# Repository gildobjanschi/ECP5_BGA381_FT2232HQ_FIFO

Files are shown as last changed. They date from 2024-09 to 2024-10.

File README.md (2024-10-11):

# ECP5/FT2232HQ Software & Hardware
This project implements a High Speed USB device using a FT2232HQ operating in synchronous FIFO mode coupled with a Lattice Semiconductor ECP5 FPGA. 

## Software
Read all the details of the bring-up steps and test code in the [Wiki](https://github.com/gildobjanschi/ECP5_BGA381_FT2232HQ_FIFO/wiki).

The diagram below will help you understand the software architecture and navigate the Verilog and C source code a bit easier.

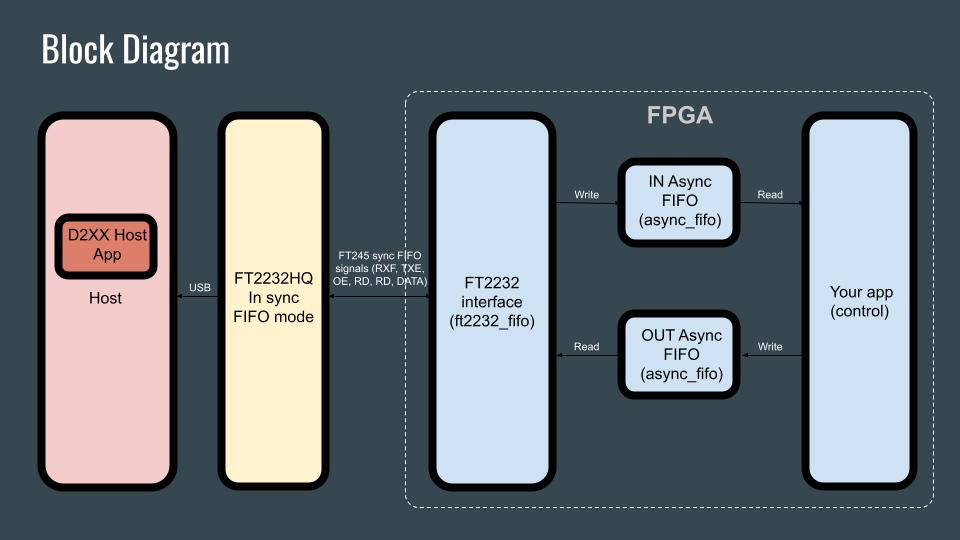
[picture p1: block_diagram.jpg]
Block Diagram


## Hardware
The board is fully functional. An [extension board](https://github.com/gildobjanschi/ECP5_BGA381_FT2232HQ_FIFO_EXT) was developed to help validate the design.

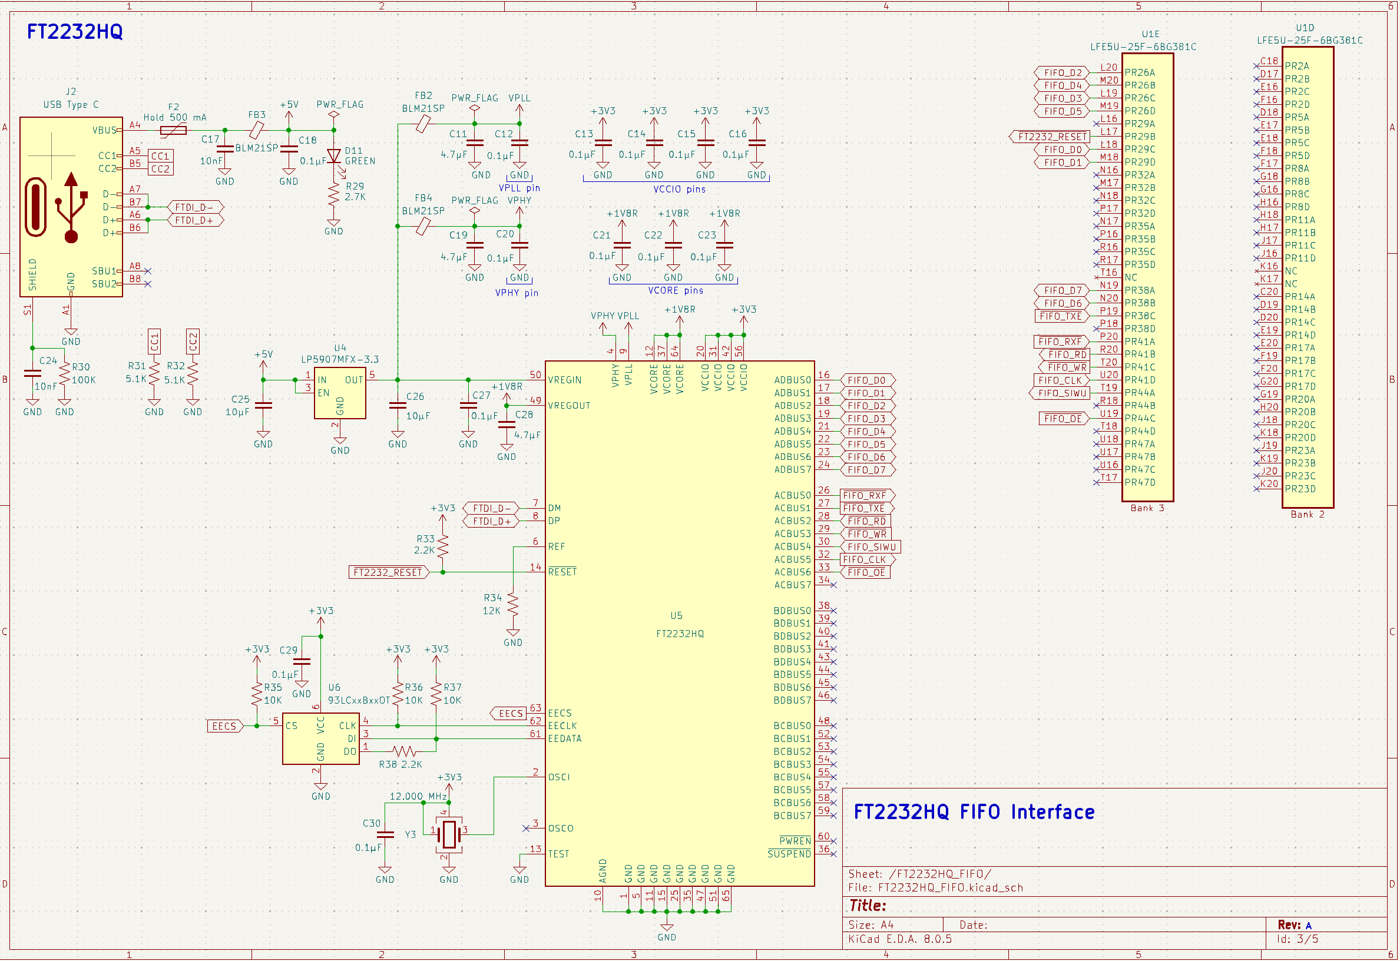
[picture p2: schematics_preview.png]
[](https://github.com/gildobjanschi/ECP5_BGA381_FT2232HQ_FIFO/blob/main/kicad/ECP5.pdf)

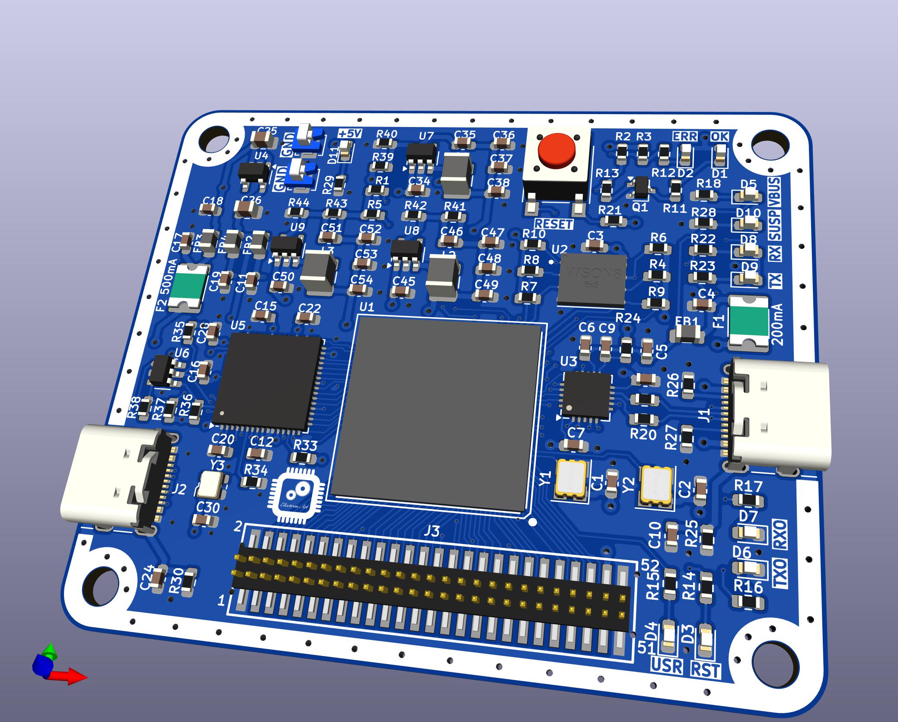
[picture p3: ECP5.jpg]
Board rendering


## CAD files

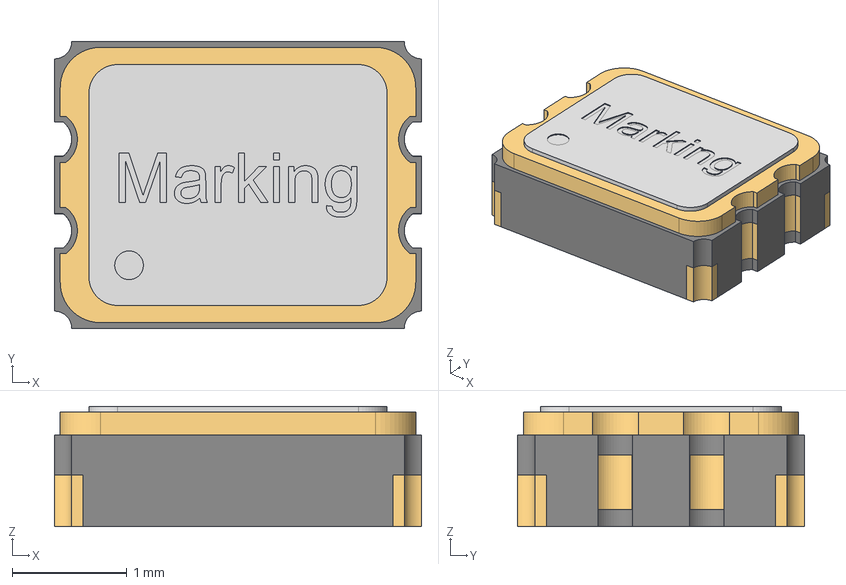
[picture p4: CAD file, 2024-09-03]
3dmodels/Wurth_830207659009.stp
3.20 x 2.50 x 1.05 mm
Pins
Cover

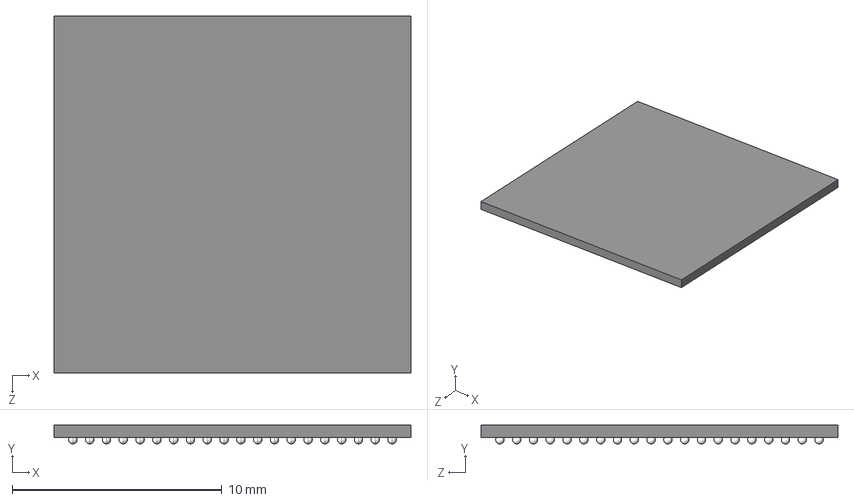
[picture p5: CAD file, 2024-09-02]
3dmodels/LFE5UM-85F-8BG381C.STEP
17.0 x 0.9 x 17.0 mm

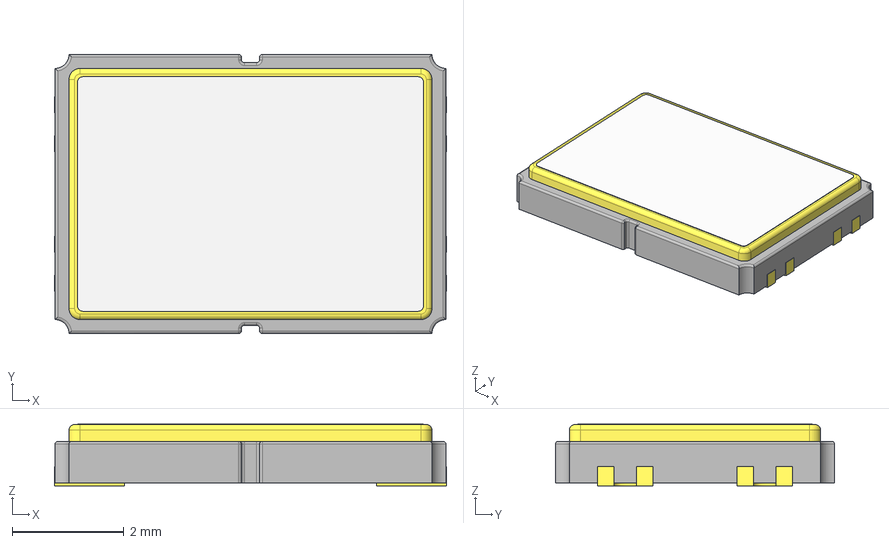
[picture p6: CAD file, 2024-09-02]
3dmodels/CRYSTAL_7050-4.step
7.02 x 5.00 x 1.11 mm
Pin
Pin001
Pin002
Pin003

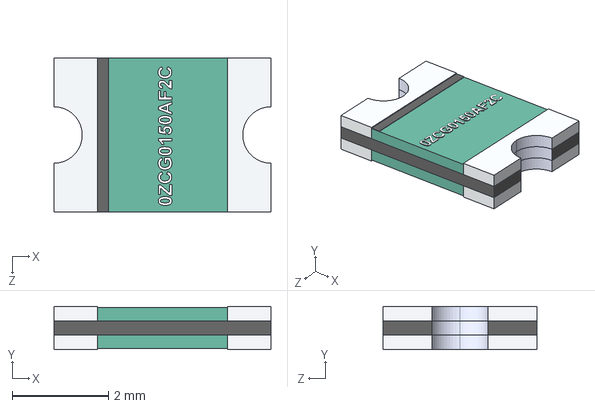
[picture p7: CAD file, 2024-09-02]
3dmodels/0ZCG-0_70mm.STEP
4.50 x 0.9 x 3.20 mm

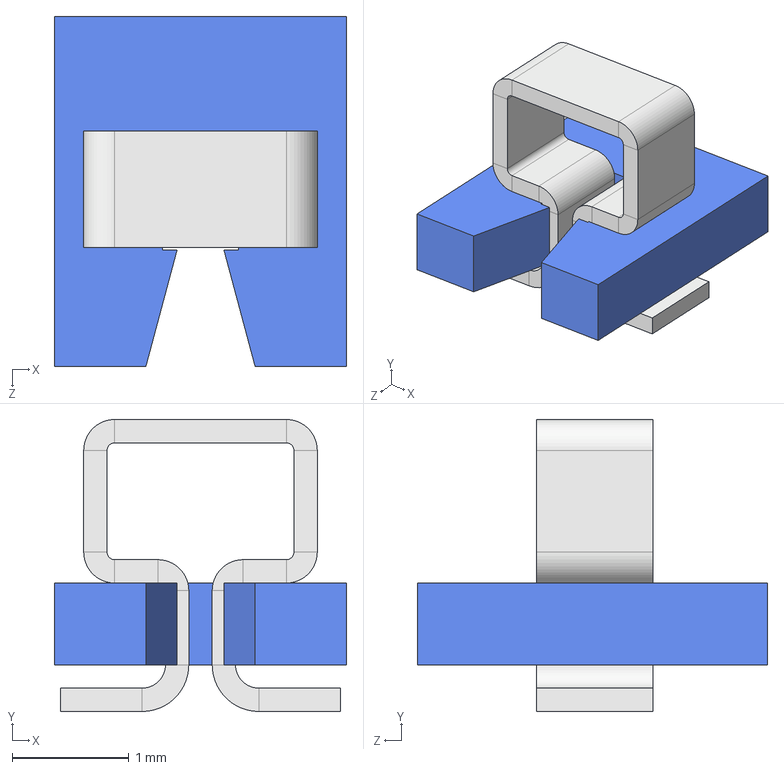
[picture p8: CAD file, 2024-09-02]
3dmodels/5197TR.step
2.50 x 2.50 x 3.00 mm
5197_insulation
5190_assembled contact

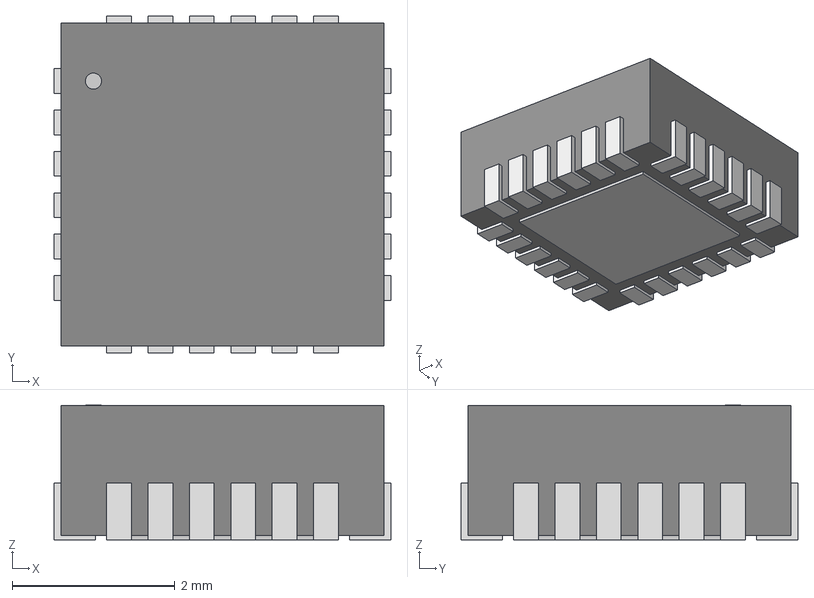
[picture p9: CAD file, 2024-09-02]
3dmodels/QFN24_4X4MC_MCH.step
4.14 x 4.14 x 1.65 mm

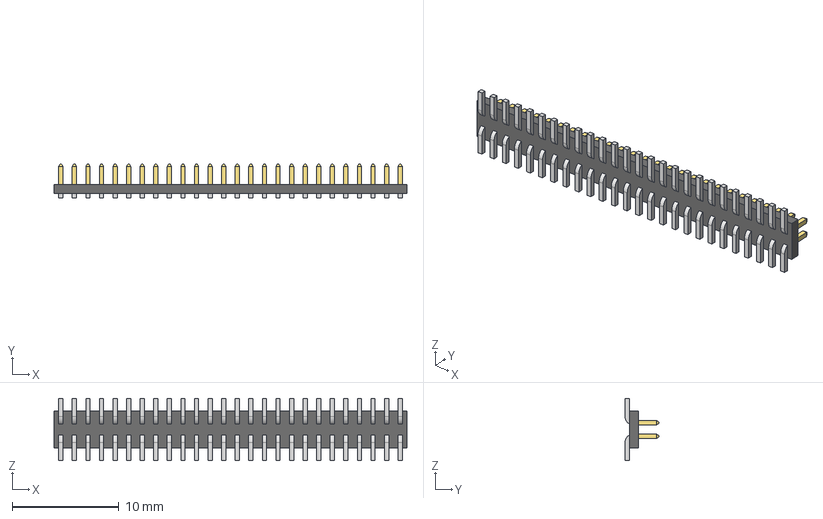
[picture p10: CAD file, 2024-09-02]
3dmodels/SAMTEC-FTS-126-02-X-DV.step
33.0 x 3.18 x 5.84 mm
FTS-126-02-L-DV_body
FTS-126-02-L-DV_pins1
FTS-126-02-L-DV_pins2

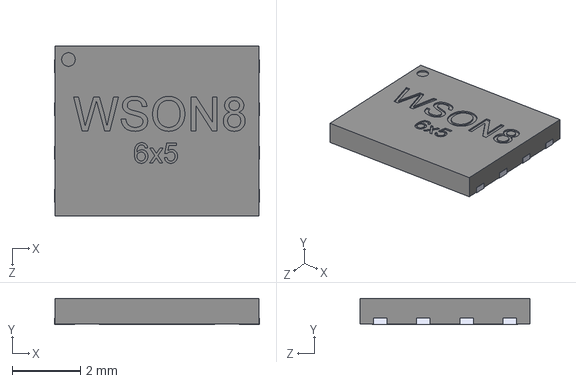
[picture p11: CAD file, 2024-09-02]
3dmodels/WSON8-6x5.STEP
6.02 x 0.77 x 5.00 mm

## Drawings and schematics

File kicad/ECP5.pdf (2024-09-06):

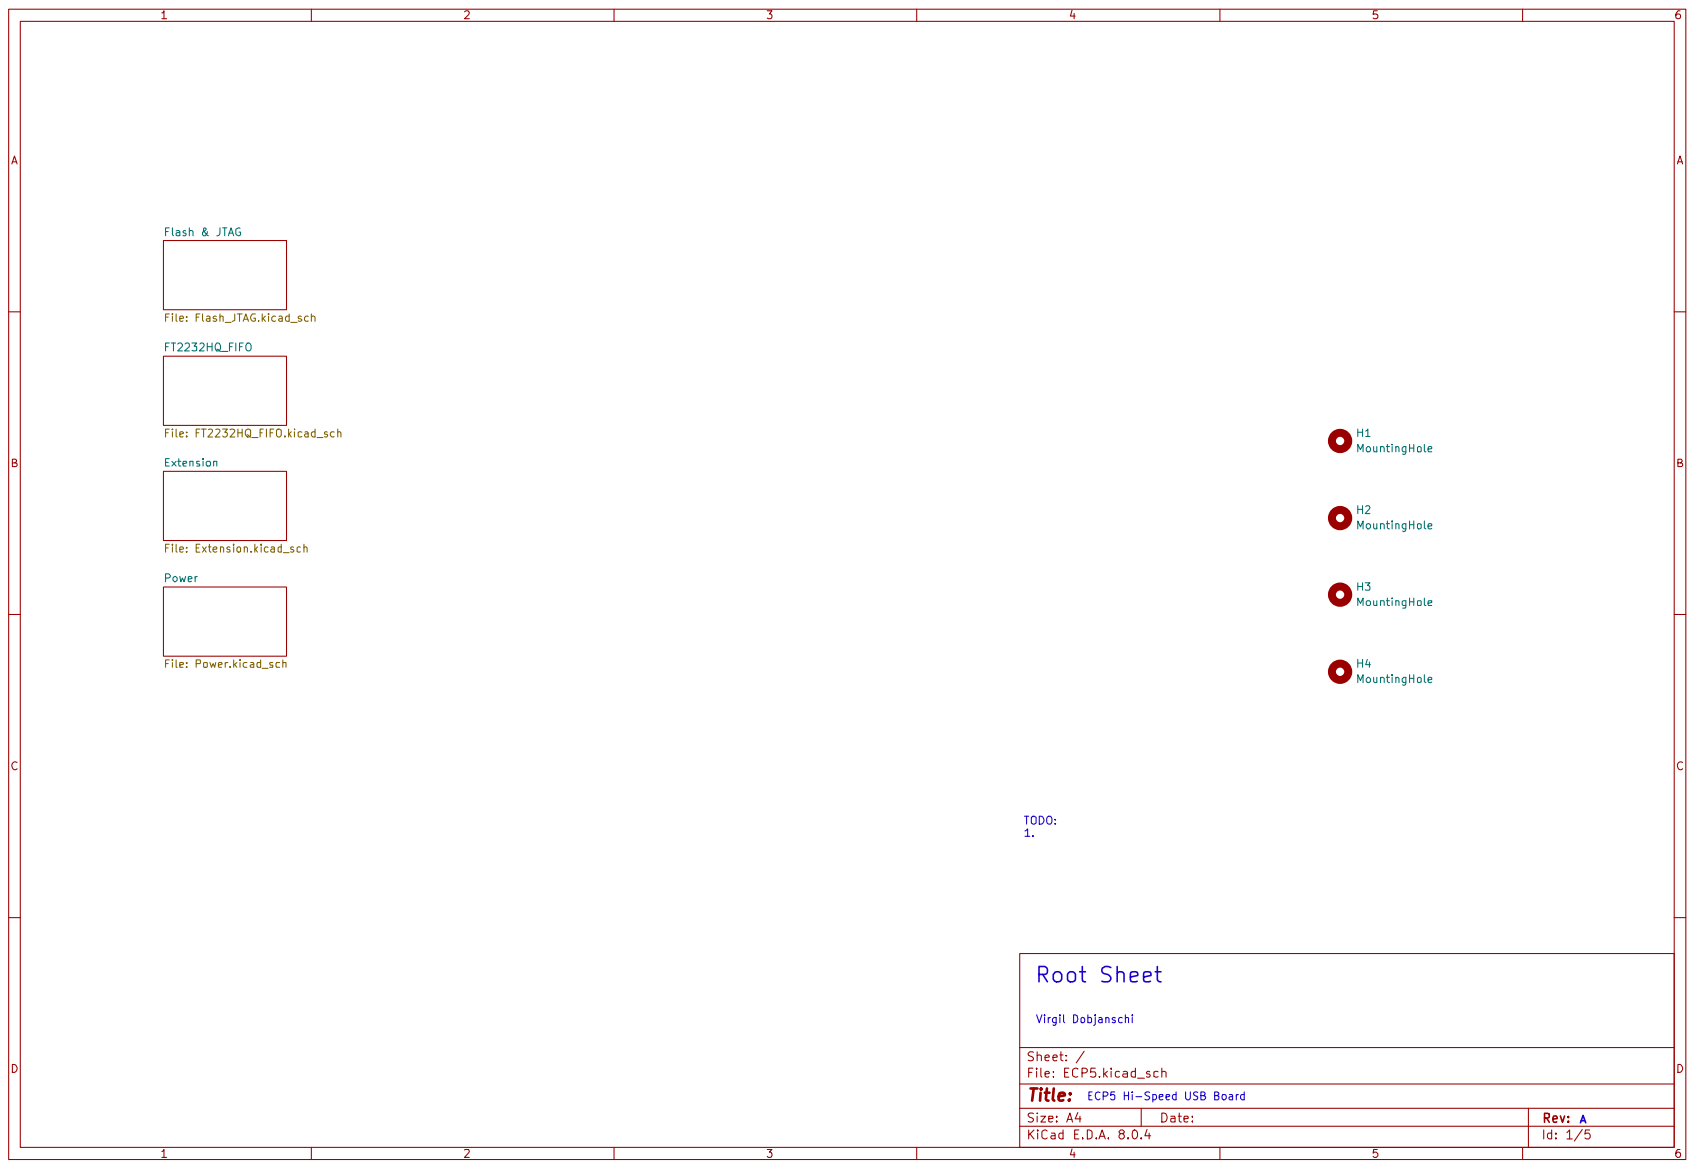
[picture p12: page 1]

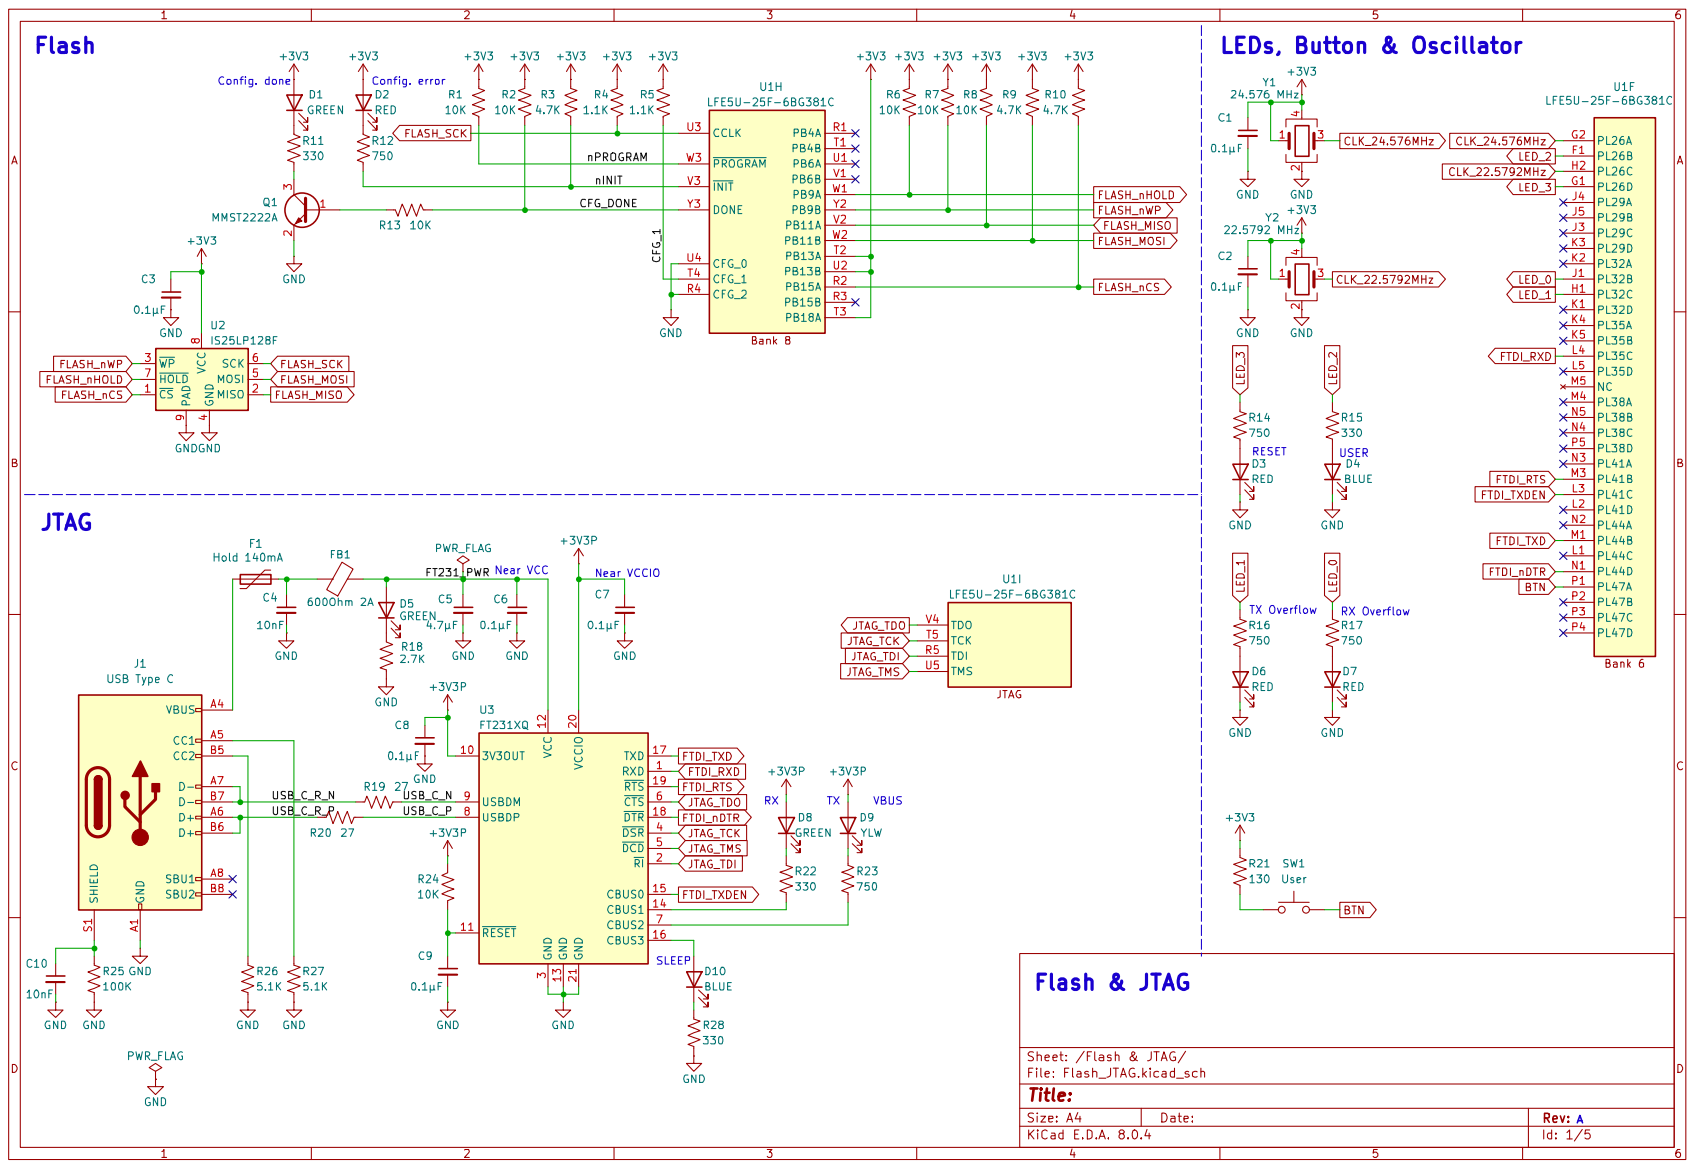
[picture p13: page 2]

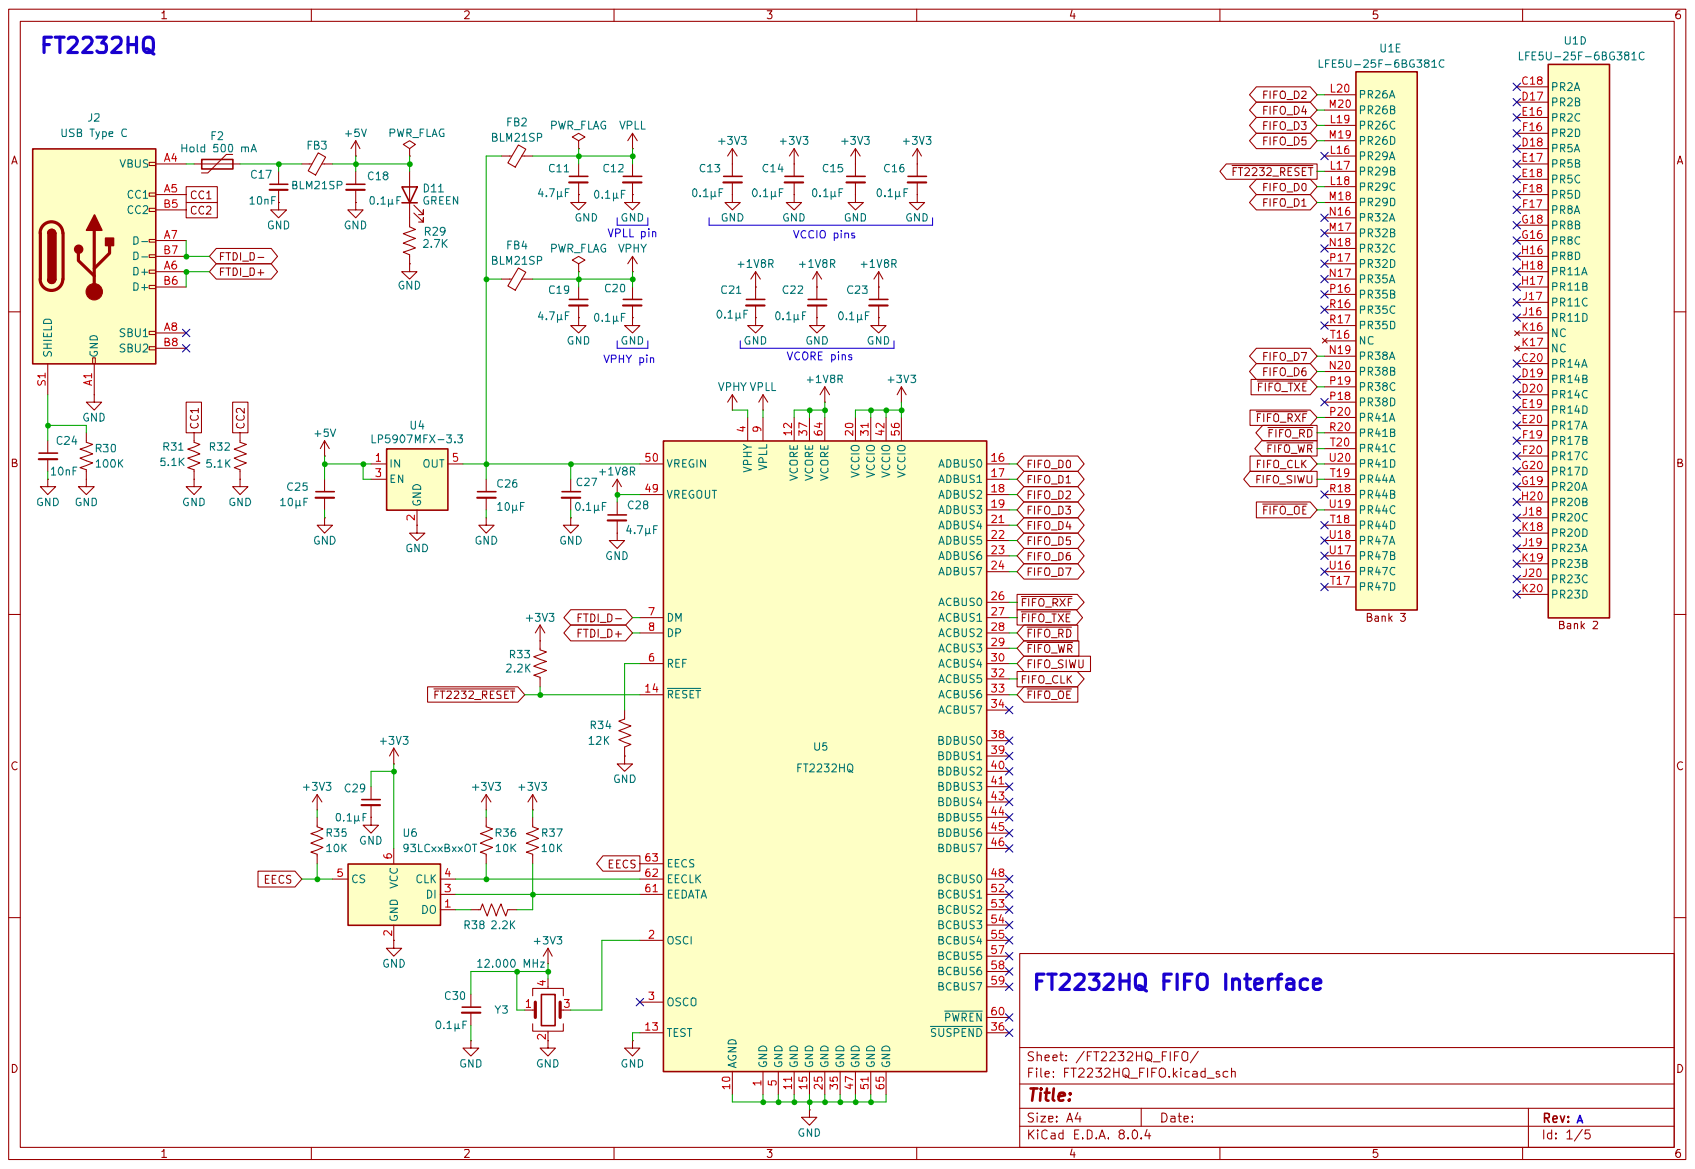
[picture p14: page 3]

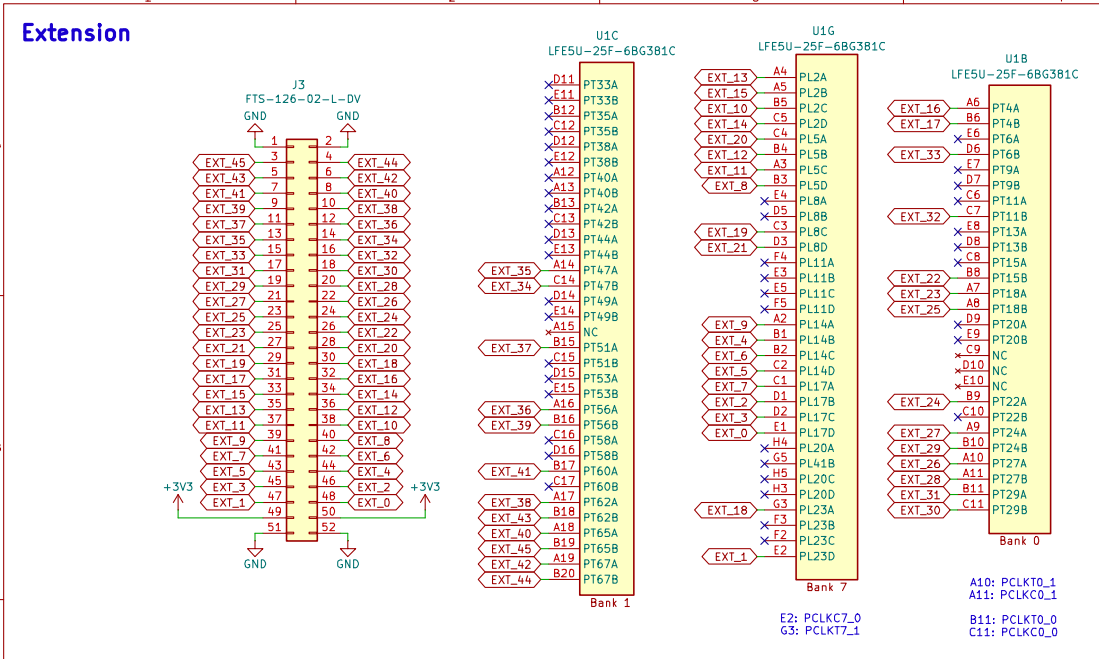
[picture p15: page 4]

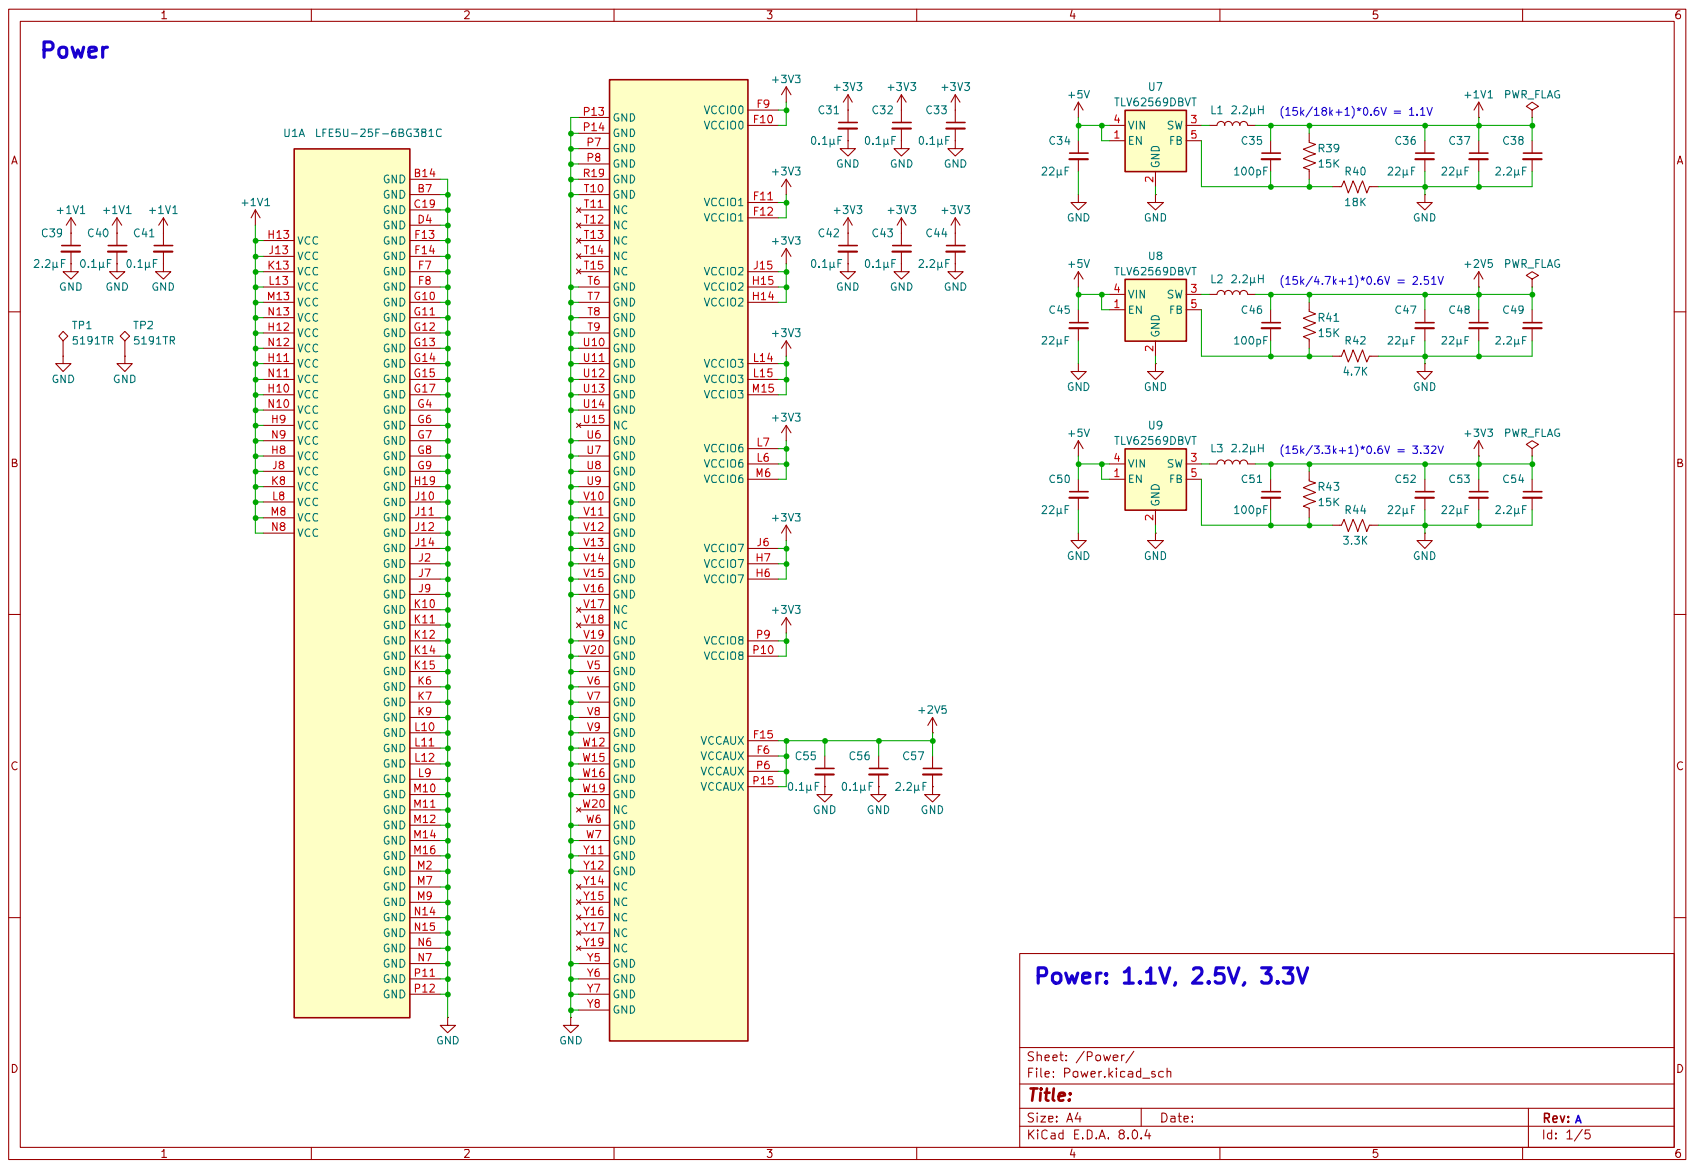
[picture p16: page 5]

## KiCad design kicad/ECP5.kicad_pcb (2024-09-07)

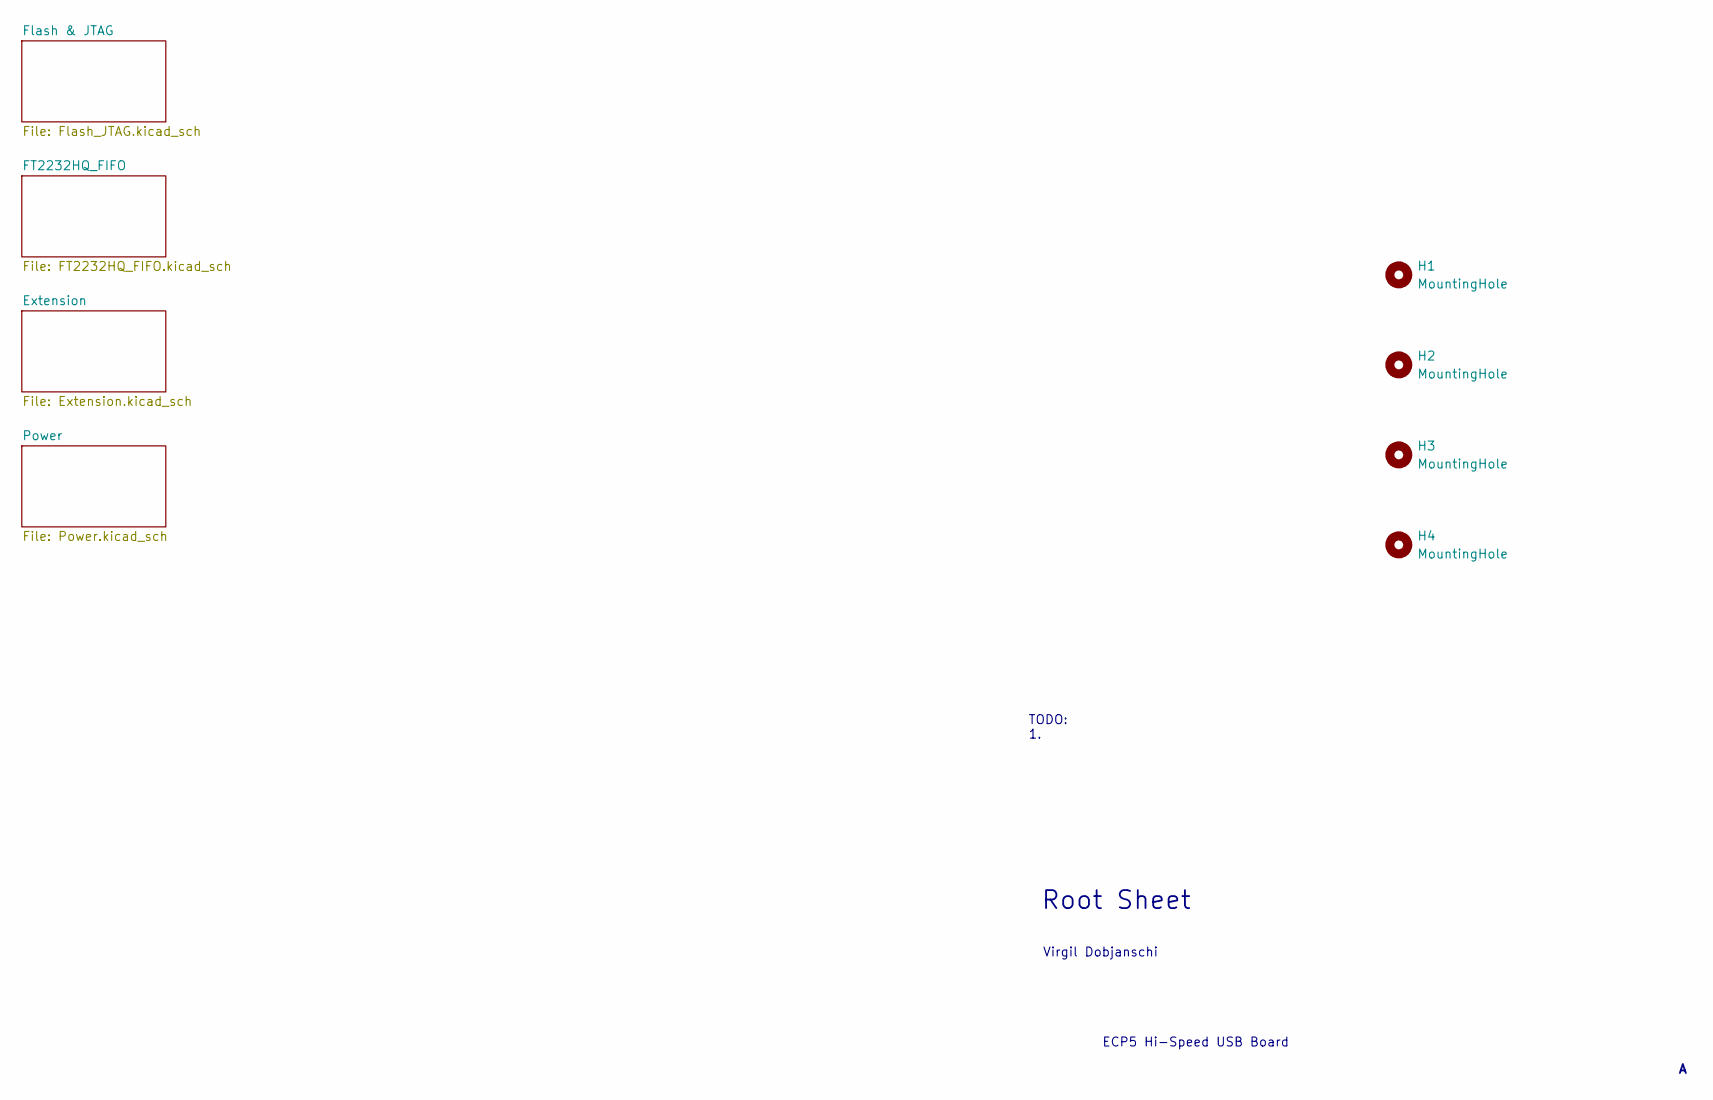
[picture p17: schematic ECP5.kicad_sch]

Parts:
H1, H2, H3, H4: MountingHole; MountingHole_3.2mm_M3

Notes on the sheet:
ECP5 Hi-Speed USB Board
Root Sheet
Virgil Dobjanschi
TODO: 1.

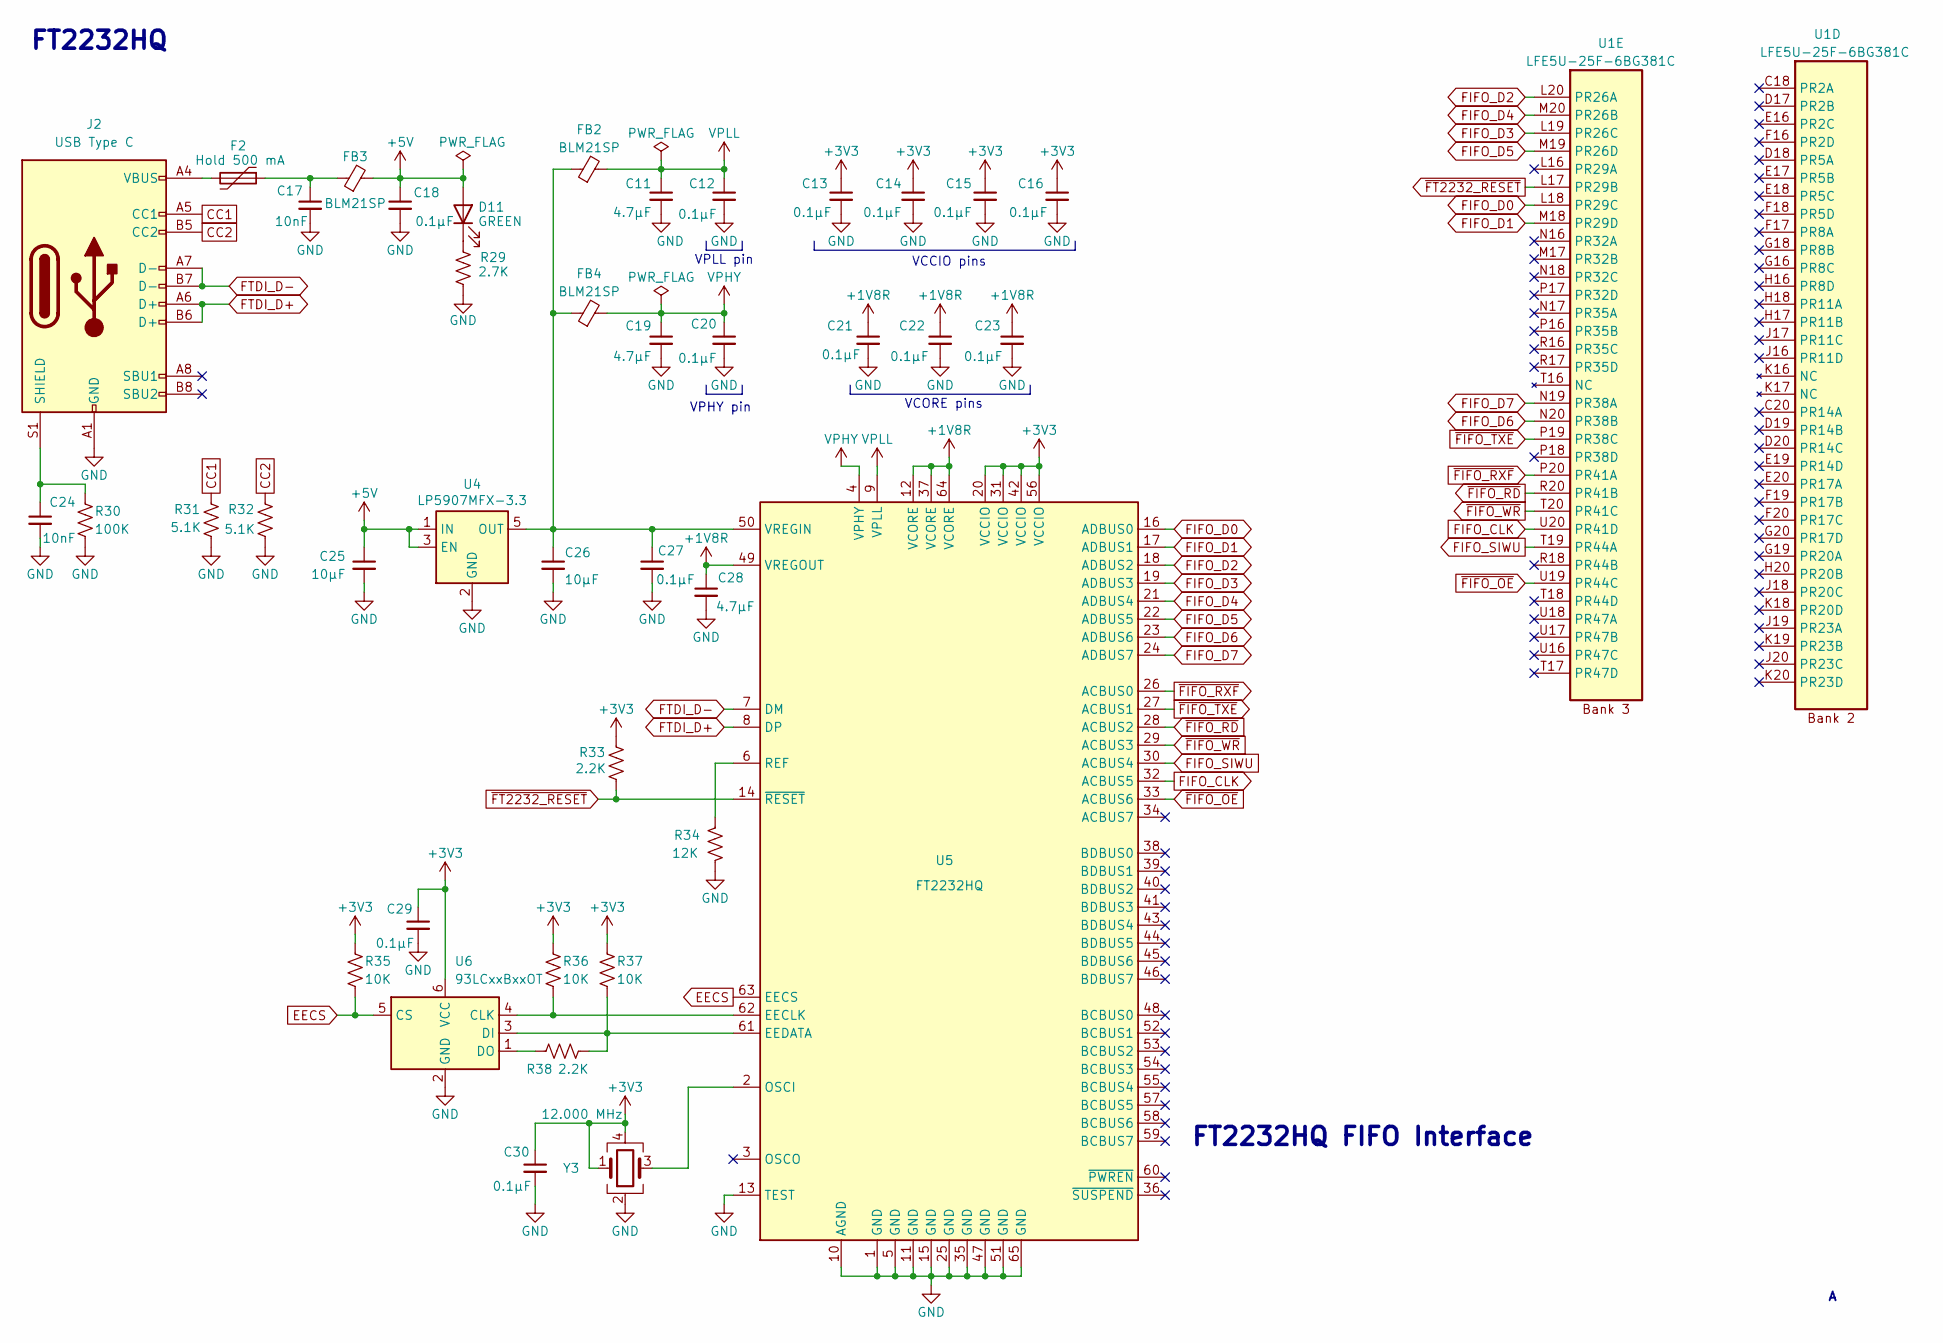
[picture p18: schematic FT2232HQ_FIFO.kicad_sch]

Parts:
C11, C19, C28: 4.7µF; C_0603_1608Metric; MPN CL10A475KP8NNNC
C12, C13, C14, C15, C16, C18, C20, C21, C22, C23, C27, C29, C30: 0.1µF; C_0603_1608Metric; MPN CL10B104KB8NNNC
C17, C24: 10nF; C_0603_1608Metric; MPN CL10B103KB8NNWC
C25, C26: 10µF; C_0805_2012Metric; MPN CL21B106KOQNNNE
D11: GREEN; LED_0603_1608Metric; MPN APT1608LZGCK
F2: Hold 500 mA; Fuse_1812_4532Metric; MPN 0ZCG0050AF2C
FB2, FB3, FB4: BLM21SP; L_0805_2012Metric; MPN BLM21SP601SN1D
J2: USB Type C; USB_C_Receptacle_GCT_USB4105-xx-A_16P_TopMnt_Horizontal; MPN USB4105-GF-A-120
R29: 2.7K; R_0603_1608Metric; MPN ERJ-3EKF2701V
R30: 100K; R_0603_1608Metric; MPN ERJ-3EKF1003V
R31, R32: 5.1K; R_0603_1608Metric; MPN ERJ-3EKF5101V
R33, R38: 2.2K; R_0603_1608Metric; MPN ERJ-3EKF2201V
R34: 12K; R_0603_1608Metric; MPN ERJ-3EKF1202V
R35, R36, R37: 10K; R_0603_1608Metric; MPN ERJ-3EKF1002V
U1: LFE5U-25F-6BG381C; BGA-381_pitch0.8mm_dia0.4mm; MPN LFE5U-25F-6BG381C
U4: LP5907MFX-3.3; SOT-23-5; MPN LP5907MFX-3.3/NOPB
U5: FT2232HQ; QFN-64-1EP_9x9mm_P0.5mm_EP4.35x4.35mm; MPN FT2232HQ-REEL
U6: 93LCxxBxxOT; SOT-23-6; MPN 93LC56BT-I/OT
Y3: 12.000 MHz; Oscillator_SMD_ECS_2520MV-xxx-xx-4Pin_2.5x2.0mm; MPN SG-210STF 12.0000ML3

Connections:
+1V8R: C21.1, C22.1, C23.1, C28.1, U5.12 (VCORE), U5.37 (VCORE), U5.49 (VREGOUT), U5.64 (VCORE)
+3V3: C13.1, C14.1, C15.1, C16.1, C29.1, C30.1, R33.1, R35.1, R36.1, R37.1, U5.20 (VCCIO), U5.31 (VCCIO), U5.42 (VCCIO), U5.56 (VCCIO), U6.6 (VCC), Y3.1, Y3.4; also elsewhere on the board
+5V: C18.1, C25.1, D11.2 (A), FB3.2, U4.1 (IN), U4.3 (EN); also elsewhere on the board
CC1: J2.A5 (CC1), R31.1
CC2: J2.B5 (CC2), R32.1
EECS: R35.2, U5.63 (EECS), U6.5 (CS)
FIFO_CLK: U1.U20 (PR41D), U5.32 (ACBUS5)
FIFO_D0: U1.L18 (PR29C), U5.16 (ADBUS0)
FIFO_D1: U1.M18 (PR29D), U5.17 (ADBUS1)
FIFO_D2: U1.L20 (PR26A), U5.18 (ADBUS2)
FIFO_D3: U1.L19 (PR26C), U5.19 (ADBUS3)
FIFO_D4: U1.M20 (PR26B), U5.21 (ADBUS4)
FIFO_D5: U1.M19 (PR26D), U5.22 (ADBUS5)
FIFO_D6: U1.N20 (PR38B), U5.23 (ADBUS6)
FIFO_D7: U1.N19 (PR38A), U5.24 (ADBUS7)
FIFO_SIWU: U1.T19 (PR44A), U5.30 (ACBUS4)
FTDI_D+: J2.A6 (D+), J2.B6 (D+), U5.8 (DP)
FTDI_D-: J2.A7 (D-), J2.B7 (D-), U5.7 (DM)
GND: C11.2, C12.2, C13.2, C14.2, C15.2, C16.2, C17.2, C18.2, C19.2, C20.2, C21.2, C22.2, C23.2, C24.2, C25.2, C26.2, C27.2, C28.2, C29.2, C30.2, J2.A1 (GND), J2.A12 (GND), J2.B1 (GND), J2.B12 (GND), R29.2, R30.2, R31.2, R32.2, R34.2, U4.2 (GND), U5.1 (GND), U5.5 (GND), U5.10 (AGND), U5.11 (GND), U5.13 (TEST), U5.15 (GND), U5.25 (GND), U5.35 (GND), U5.47 (GND), U5.51 (GND), U5.65 (GND), U6.2 (GND), Y3.2; also elsewhere on the board
unnamed: C17.1, F2.1, FB3.1
unnamed: D11.1 (K), R29.1
unnamed: F2.2, J2.A4 (VBUS), J2.A9 (VBUS), J2.B4 (VBUS), J2.B9 (VBUS)
unnamed: C24.1, J2.S1 (SHIELD), R30.1
unnamed: C26.1, C27.1, FB2.1, FB4.1, U4.5 (OUT), U5.50 (VREGIN)
unnamed: R36.2, U5.62 (EECLK), U6.4 (CLK)
unnamed: R37.2, R38.2, U5.61 (EEDATA), U6.3 (DI)
unnamed: U5.2 (OSCI), Y3.3
unnamed: R34.1, U5.6 (REF)
unnamed: R38.1, U6.1 (DO)
VPHY: C19.1, C20.1, FB4.2, U5.4 (VPHY)
VPLL: C11.1, C12.1, FB2.2, U5.9 (VPLL)
~FIFO_OE: U1.U19 (PR44C), U5.33 (ACBUS6)
~FIFO_RD: U1.R20 (PR41B), U5.28 (ACBUS2)
~FIFO_RXF: U1.P20 (PR41A), U5.26 (ACBUS0)
~FIFO_TXE: U1.P19 (PR38C), U5.27 (ACBUS1)
~FIFO_WR: U1.T20 (PR41C), U5.29 (ACBUS3)
~FT2232_RESET: R33.2, U1.L17 (PR29B), U5.14 (~RESET)

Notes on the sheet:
VPHY pin
VPLL pin
FT2232HQ
VCCIO pins
VCORE pins
FT2232HQ FIFO Interface

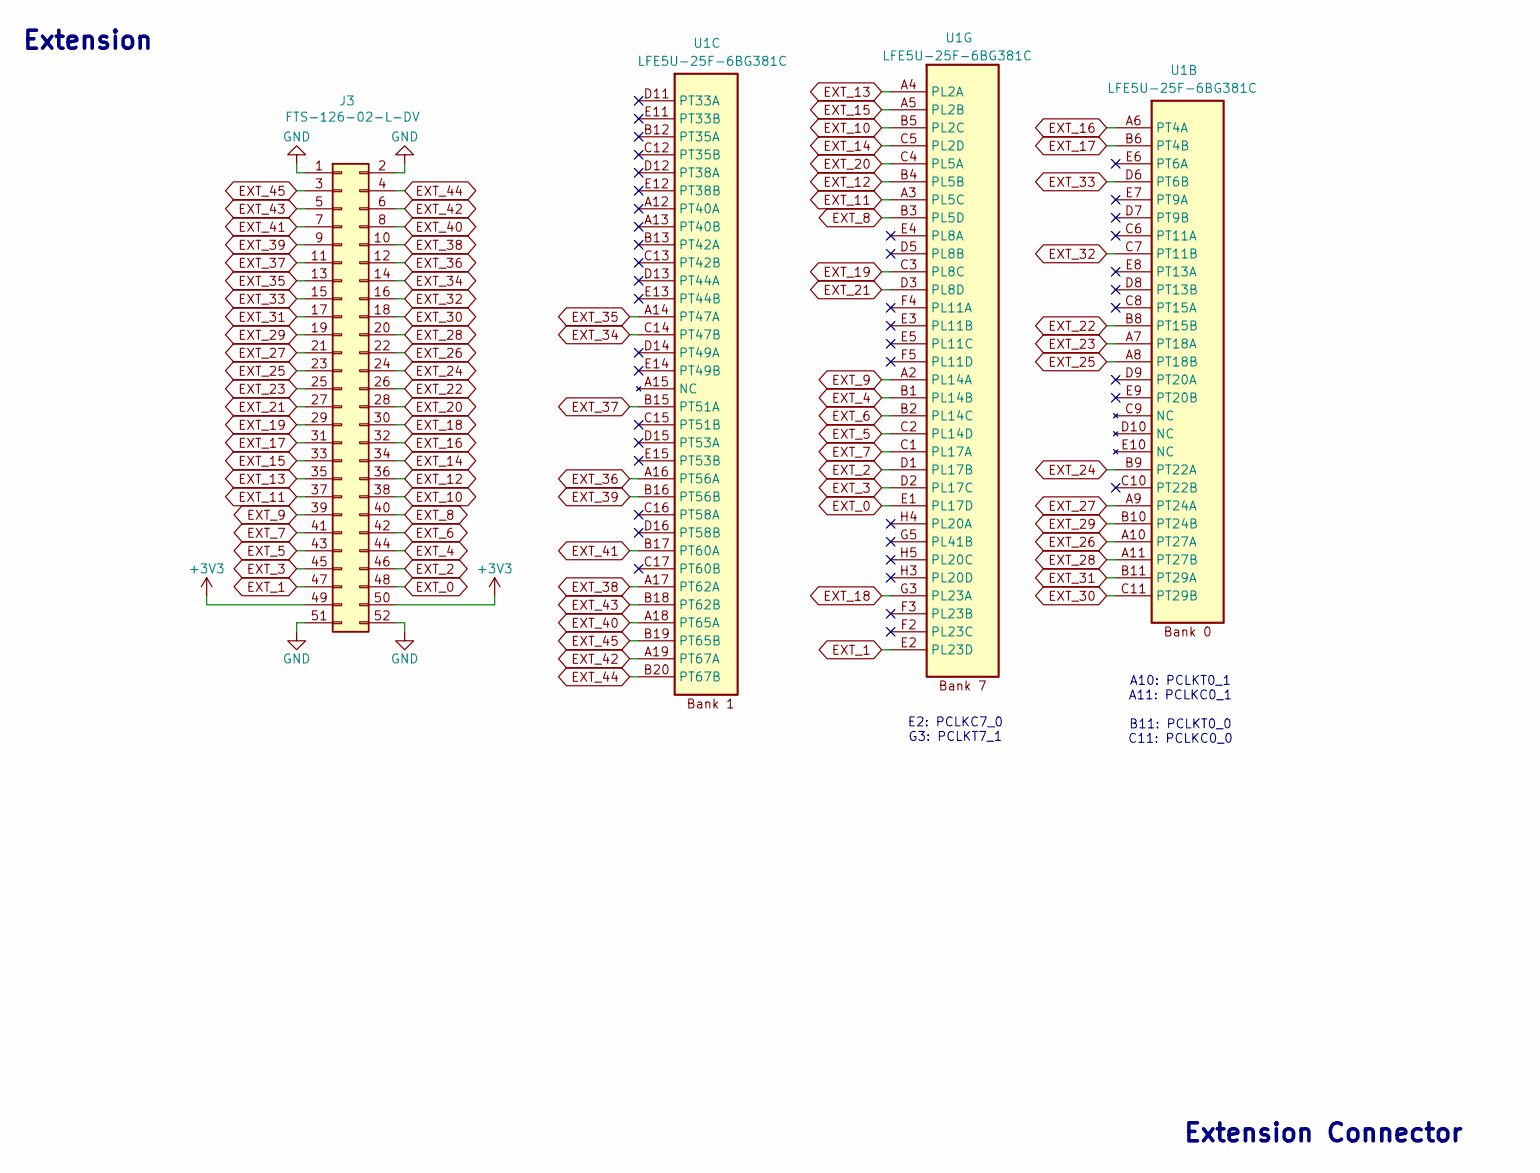
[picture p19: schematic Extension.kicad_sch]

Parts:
J3: FTS-126-02-L-DV; SAMTEC-FTS-126-02-X-DV; MPN FTS-126-02-L-DV
U1: LFE5U-25F-6BG381C; BGA-381_pitch0.8mm_dia0.4mm; MPN LFE5U-25F-6BG381C

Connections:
+3V3: J3.49, J3.50; also elsewhere on the board
EXT_0: J3.48, U1.E1 (PL17D)
EXT_1: J3.47, U1.E2 (PL23D)
EXT_2: J3.46, U1.D1 (PL17B)
EXT_3: J3.45, U1.D2 (PL17C)
EXT_4: J3.44, U1.B1 (PL14B)
EXT_5: J3.43, U1.C2 (PL14D)
EXT_6: J3.42, U1.B2 (PL14C)
EXT_7: J3.41, U1.C1 (PL17A)
EXT_8: J3.40, U1.B3 (PL5D)
EXT_9: J3.39, U1.A2 (PL14A)
EXT_10: J3.38, U1.B5 (PL2C)
EXT_11: J3.37, U1.A3 (PL5C)
EXT_12: J3.36, U1.B4 (PL5B)
EXT_13: J3.35, U1.A4 (PL2A)
EXT_14: J3.34, U1.C5 (PL2D)
EXT_15: J3.33, U1.A5 (PL2B)
EXT_16: J3.32, U1.A6 (PT4A)
EXT_17: J3.31, U1.B6 (PT4B)
EXT_18: J3.30, U1.G3 (PL23A)
EXT_19: J3.29, U1.C3 (PL8C)
EXT_20: J3.28, U1.C4 (PL5A)
EXT_21: J3.27, U1.D3 (PL8D)
EXT_22: J3.26, U1.B8 (PT15B)
EXT_23: J3.25, U1.A7 (PT18A)
EXT_24: J3.24, U1.B9 (PT22A)
EXT_25: J3.23, U1.A8 (PT18B)
EXT_26: J3.22, U1.A10 (PT27A)
EXT_27: J3.21, U1.A9 (PT24A)
EXT_28: J3.20, U1.A11 (PT27B)
EXT_29: J3.19, U1.B10 (PT24B)
EXT_30: J3.18, U1.C11 (PT29B)
EXT_31: J3.17, U1.B11 (PT29A)
EXT_32: J3.16, U1.C7 (PT11B)
EXT_33: J3.15, U1.D6 (PT6B)
EXT_34: J3.14, U1.C14 (PT47B)
EXT_35: J3.13, U1.A14 (PT47A)
EXT_36: J3.12, U1.A16 (PT56A)
EXT_37: J3.11, U1.B15 (PT51A)
EXT_38: J3.10, U1.A17 (PT62A)
EXT_39: J3.9, U1.B16 (PT56B)
EXT_40: J3.8, U1.A18 (PT65A)
EXT_41: J3.7, U1.B17 (PT60A)
EXT_42: J3.6, U1.A19 (PT67A)
EXT_43: J3.5, U1.B18 (PT62B)
EXT_44: J3.4, U1.B20 (PT67B)
EXT_45: J3.3, U1.B19 (PT65B)
GND: J3.1, J3.2, J3.51, J3.52; also elsewhere on the board

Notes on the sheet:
E2: PCLKC7_0 G3: PCLKT7_1
Extension Connector
Extension
A10: PCLKT0_1 A11: PCLKC0_1 B11: PCLKT0_0 C11: PCLKC0_0

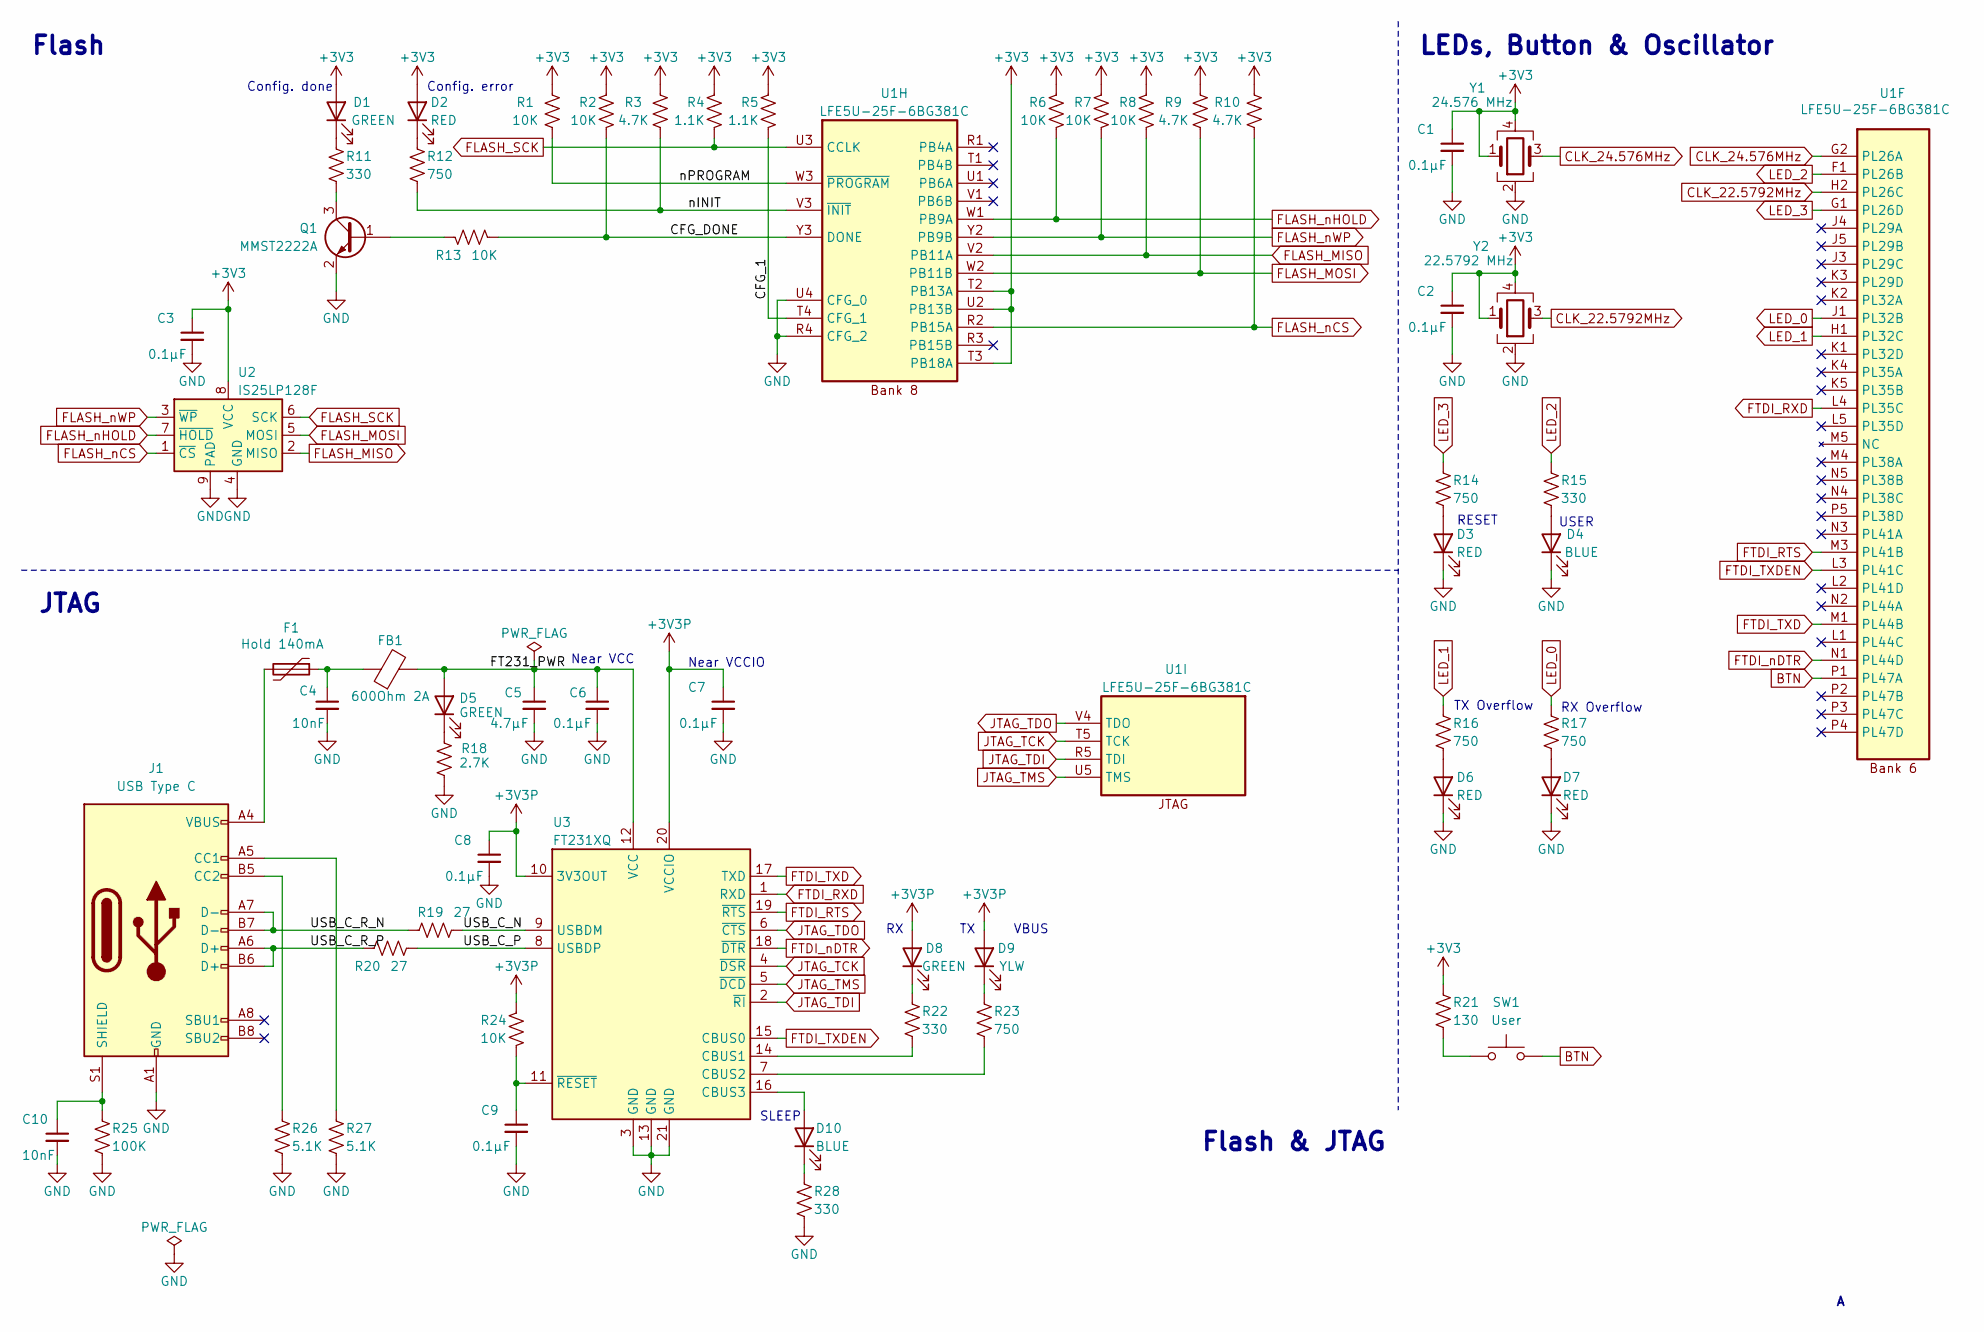
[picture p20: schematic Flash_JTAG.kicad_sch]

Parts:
C1, C2, C3, C6, C7, C8, C9: 0.1µF; C_0603_1608Metric; MPN CL10B104KB8NNNC
C4, C10: 10nF; C_0603_1608Metric; MPN CL10B103KB8NNWC
C5: 4.7µF; C_0603_1608Metric; MPN CL10A475KP8NNNC
D1, D5, D8: GREEN; LED_0603_1608Metric; MPN APT1608LZGCK
D2, D3, D6, D7: RED; LED_0603_1608Metric; MPN APT1608LSECK/J3-PRV
D4, D10: BLUE; LED_0603_1608Metric; MPN APT1608LVBC/D
D9: YLW; LED_0603_1608Metric; MPN APT1608LSYCK/J3-PRV
F1: Hold 140mA; Fuse_1812_4532Metric; MPN 0ZCG0014FF2C
FB1: 600Ohm 2A; L_0805_2012Metric; MPN 78279220601
J1: USB Type C; USB_C_Receptacle_GCT_USB4105-xx-A_16P_TopMnt_Horizontal; MPN USB4105-GF-A-120
Q1: MMST2222A; SOT-323_SC-70; MPN MMST2222A-7-F
R1, R2, R6, R7, R8, R13, R24: 10K; R_0603_1608Metric; MPN ERJ-3EKF1002V
R3, R9, R10: 4.7K; R_0603_1608Metric; MPN ERJ-3EKF4701V
R4, R5: 1.1K; R_0603_1608Metric; MPN ERJ-3EKF1101V
R11, R15, R22, R28: 330; R_0603_1608Metric; MPN ERJ-3EKF3300V
R12, R14, R16, R17, R23: 750; R_0603_1608Metric; MPN ERJ-3EKF7500V
R18: 2.7K; R_0603_1608Metric; MPN ERJ-3EKF2701V
R19, R20: 27; R_0603_1608Metric; MPN ERJ-3EKF27R0V
R21: 130; R_0603_1608Metric; MPN ERJ-3EKF1300V
R25: 100K; R_0603_1608Metric; MPN ERJ-3EKF1003V
R26, R27: 5.1K; R_0603_1608Metric; MPN ERJ-3EKF5101V
SW1: User; SW_SPST_PTS645; MPN PTS645SK43SMTR92 LFS
U1: LFE5U-25F-6BG381C; BGA-381_pitch0.8mm_dia0.4mm; MPN LFE5U-25F-6BG381C
U2: IS25LP128F; WSON-8-1EP_6x5mm_P1.27mm_EP3.4x4.3mm; MPN IS25LP128-JKLE
U3: FT231XQ; QFN-20-1EP_4x4mm_P0.5mm_EP2.5x2.5mm; MPN FT231XQ-R
Y1: 24.576 MHz; Oscillator_SMD_Abracon_ASE-4Pin_3.2x2.5mm; MPN 830207659209
Y2: 22.5792 MHz; Oscillator_SMD_Abracon_ASE-4Pin_3.2x2.5mm; MPN 830207659009

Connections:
+3V3: C1.1, C2.1, C3.1, D1.2 (A), D2.2 (A), R1.2, R2.1, R3.2, R4.1, R5.1, R6.1, R7.1, R8.1, R9.2, R10.2, R21.1, U1.T2 (PB13A), U1.T3 (PB18A), U1.U2 (PB13B), U2.8 (VCC), Y1.1, Y1.4, Y2.1, Y2.4; also elsewhere on the board
+3V3P: C7.1, C8.1, D8.2 (A), D9.2 (A), R24.1, U3.10 (3V3OUT), U3.20 (VCCIO)
/Flash & JTAG/CFG_1: R5.2, U1.T4 (CFG_1)
/Flash & JTAG/CFG_DONE: R2.2, R13.2, U1.Y3 (DONE)
/Flash & JTAG/FT231_PWR: C5.1, C6.1, D5.2 (A), FB1.2, U3.12 (VCC)
/Flash & JTAG/USB_C_N: R19.2, U3.9 (USBDM)
/Flash & JTAG/USB_C_P: R20.2, U3.8 (USBDP)
/Flash & JTAG/USB_C_R_N: J1.A7 (D-), J1.B7 (D-), R19.1
/Flash & JTAG/USB_C_R_P: J1.A6 (D+), J1.B6 (D+), R20.1
/Flash & JTAG/nINIT: R3.1, R12.2, U1.V3 (~INIT)
/Flash & JTAG/nPROGRAM: R1.1, U1.W3 (~PROGRAM)
BTN: SW1.2, U1.P1 (PL47A)
CLK_22.5792MHz: U1.H2 (PL26C), Y2.3
CLK_24.576MHz: U1.G2 (PL26A), Y1.3
FLASH_MISO: R8.2, U1.V2 (PB11A), U2.2 (MISO)
FLASH_MOSI: R9.1, U1.W2 (PB11B), U2.5 (MOSI)
FLASH_SCK: R4.2, U1.U3 (CCLK), U2.6 (SCK)
FLASH_nCS: R10.1, U1.R2 (PB15A), U2.1 (~CS)
FLASH_nHOLD: R6.2, U1.W1 (PB9A), U2.7 (~HOLD)
FLASH_nWP: R7.2, U1.Y2 (PB9B), U2.3 (~WP)
FTDI_RTS: U1.M3 (PL41B), U3.19 (~RTS)
FTDI_RXD: U1.L4 (PL35C), U3.1 (RXD)
FTDI_TXD: U1.M1 (PL44B), U3.17 (TXD)
FTDI_TXDEN: U1.L3 (PL41C), U3.15 (CBUS0)
FTDI_nDTR: U1.N1 (PL44D), U3.18 (~DTR)
GND: C1.2, C2.2, C3.2, C4.2, C5.2, C6.2, C7.2, C8.2, C9.2, C10.2, D3.1 (K), D4.1 (K), D6.1 (K), D7.1 (K), J1.A1 (GND), J1.A12 (GND), J1.B1 (GND), J1.B12 (GND), Q1.2 (E), R18.2, R25.2, R26.2, R27.2, R28.2, U1.R4 (CFG_2), U1.U4 (CFG_0), U2.4 (GND), U2.9 (PAD), U3.3 (GND), U3.13 (GND), U3.21 (GND), Y1.2, Y2.2; also elsewhere on the board
JTAG_TCK: U1.T5 (TCK), U3.4 (~DSR)
JTAG_TDI: U1.R5 (TDI), U3.2 (~RI)
JTAG_TDO: U1.V4 (TDO), U3.6 (~CTS)
JTAG_TMS: U1.U5 (TMS), U3.5 (~DCD)
LED_0: R17.1, U1.J1 (PL32B)
LED_1: R16.1, U1.H1 (PL32C)
LED_2: R15.1, U1.F1 (PL26B)
LED_3: R14.1, U1.G1 (PL26D)
unnamed: C4.1, F1.1, FB1.1
unnamed: D1.1 (K), R11.1
unnamed: D2.1 (K), R12.1
unnamed: D3.2 (A), R14.2
unnamed: D4.2 (A), R15.2
unnamed: D5.1 (K), R18.1
unnamed: D6.2 (A), R16.2
unnamed: D7.2 (A), R17.2
unnamed: D8.1 (K), R22.1
unnamed: D9.1 (K), R23.1
unnamed: D10.2 (A), U3.16 (CBUS3)
unnamed: D10.1 (K), R28.1
unnamed: F1.2, J1.A4 (VBUS), J1.A9 (VBUS), J1.B4 (VBUS), J1.B9 (VBUS)
unnamed: J1.A5 (CC1), R27.1
unnamed: J1.B5 (CC2), R26.1
unnamed: C10.1, J1.S1 (SHIELD), R25.1
unnamed: Q1.1 (B), R13.1
unnamed: Q1.3 (C), R11.2
unnamed: R21.2, SW1.1
unnamed: R22.2, U3.14 (CBUS1)
unnamed: R23.2, U3.7 (CBUS2)
unnamed: C9.1, R24.2, U3.11 (~RESET)

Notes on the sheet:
Near VCCIO
Flash
Near VCC
Flash & JTAG
SLEEP
RX Overflow
LEDs, Button & Oscillator
RESET
VBUS
Config. done
JTAG
Config. error
USER
TX Overflow

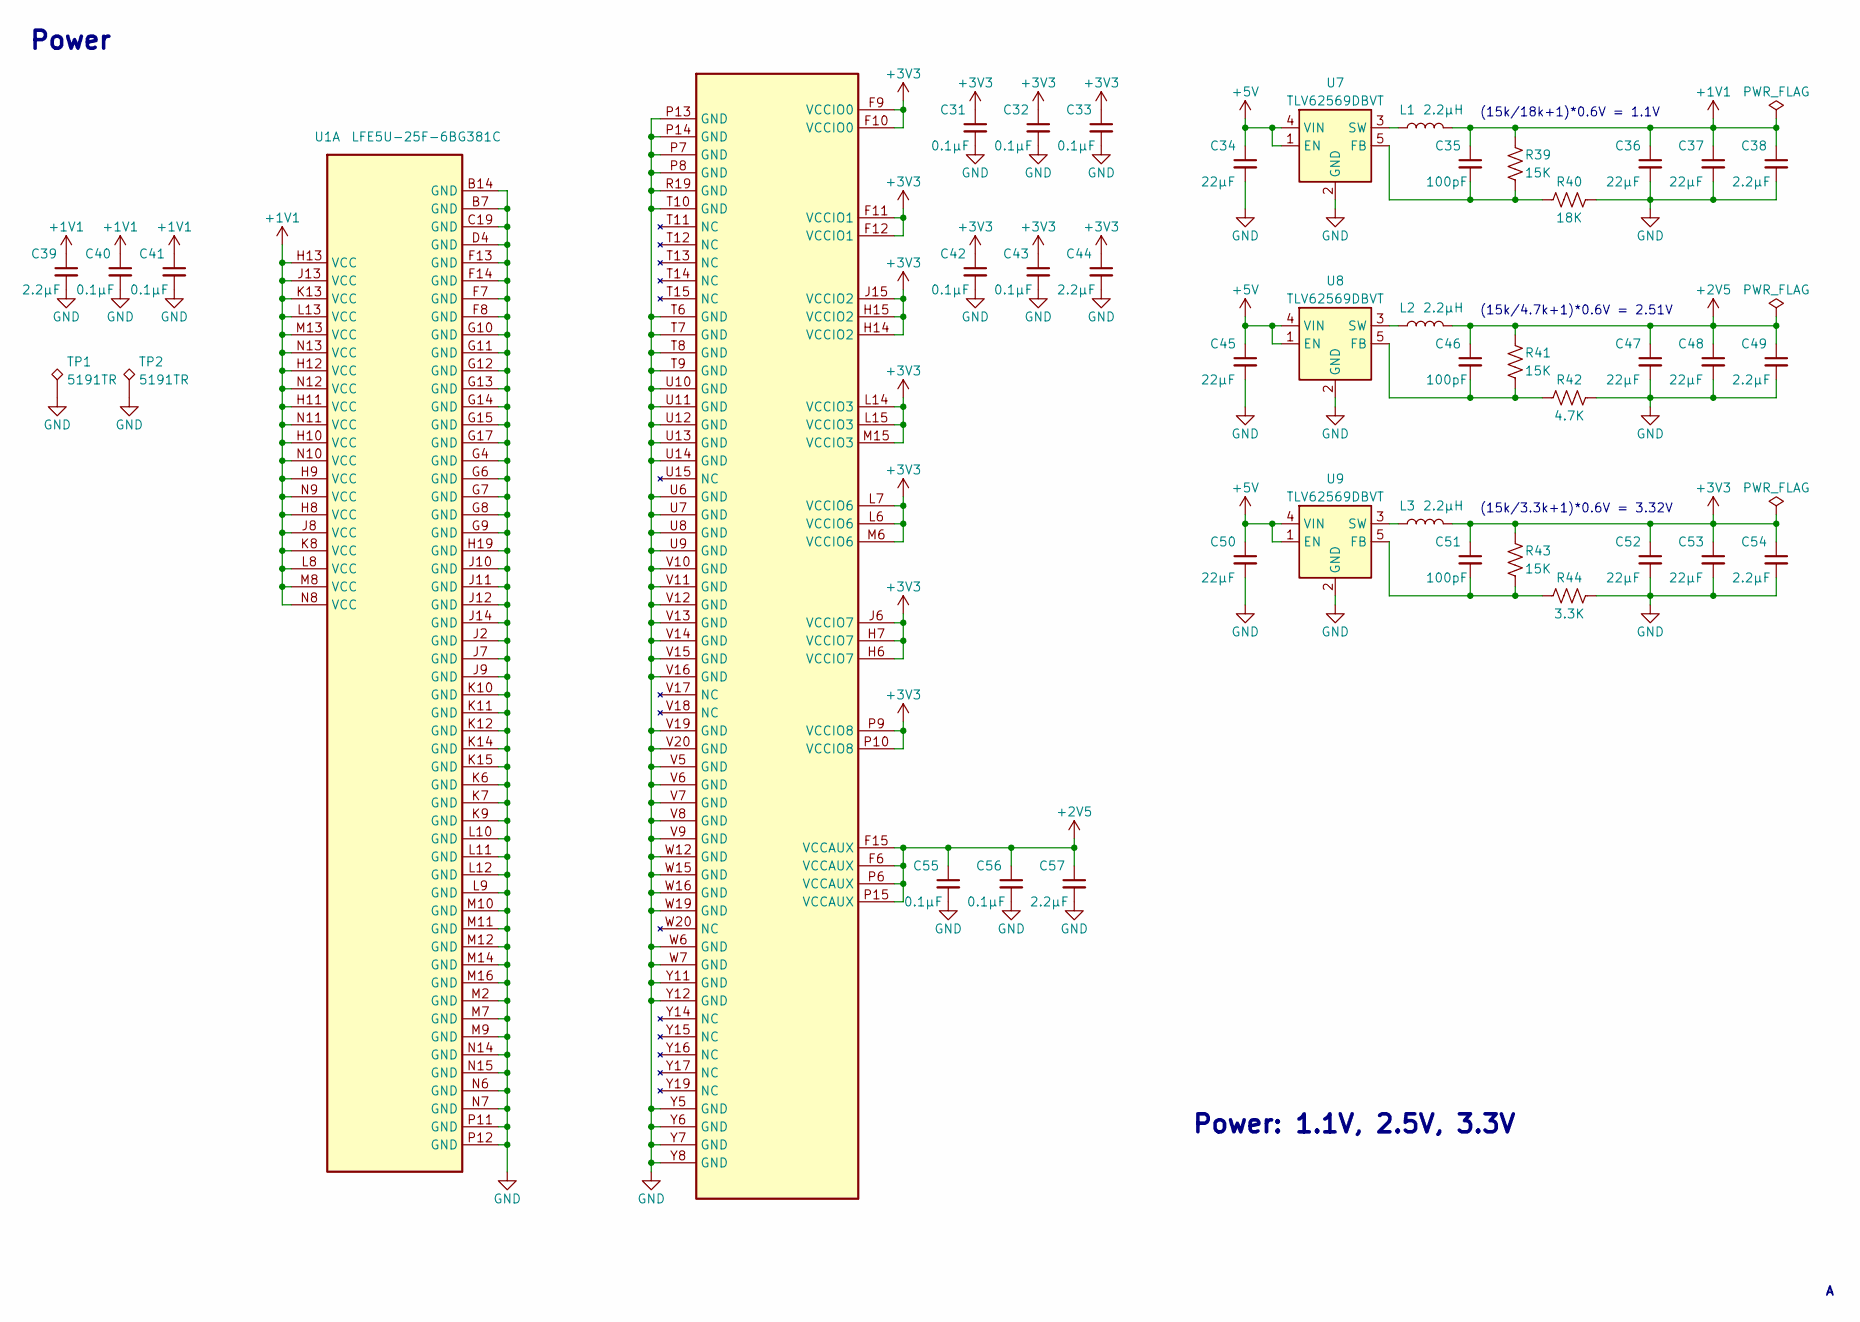
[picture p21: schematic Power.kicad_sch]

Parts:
C31, C32, C33, C40, C41, C42, C43, C55, C56: 0.1µF; C_0603_1608Metric; MPN CL10B104KB8NNNC
C34, C36, C37, C45, C47, C48, C50, C52, C53: 22µF; C_0603_1608Metric; MPN CL10A226MP8NUNE
C35, C46, C51: 100pF; C_0603_1608Metric; MPN CL10C101FB81PNC
C38, C39, C44, C49, C54, C57: 2.2µF; C_0603_1608Metric; MPN CL10B225KP8NNNC
L1, L2, L3: 2.2µH; L_1210_3225Metric; MPN DFE322512F-2R2M=P2
R39, R41, R43: 15K; R_0603_1608Metric; MPN ERJ-3EKF1502V
R40: 18K; R_0603_1608Metric; MPN ERJ-3EKF1802V
R42: 4.7K; R_0603_1608Metric; MPN ERJ-3EKF4701V
R44: 3.3K; R_0603_1608Metric; MPN ERJ-3EKF3301V
TP1, TP2: 5191TR; KEYSTONE_5197TR; MPN 5191TR
U1: LFE5U-25F-6BG381C; BGA-381_pitch0.8mm_dia0.4mm; MPN LFE5U-25F-6BG381C
U7, U8, U9: TLV62569DBVT; SOT-23-5; MPN TLV62569DBVT

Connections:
+1V1: C35.1, C36.1, C37.1, C38.1, C39.1, C40.1, C41.1, L1.2, R39.1, U1.H8 (VCC), U1.H9 (VCC), U1.H10 (VCC), U1.H11 (VCC), U1.H12 (VCC), U1.H13 (VCC), U1.J8 (VCC), U1.J13 (VCC), U1.K8 (VCC), U1.K13 (VCC), U1.L8 (VCC), U1.L13 (VCC), U1.M8 (VCC), U1.M13 (VCC), U1.N8 (VCC), U1.N9 (VCC), U1.N10 (VCC), U1.N11 (VCC), U1.N12 (VCC), U1.N13 (VCC)
+2V5: C46.1, C47.1, C48.1, C49.1, C55.1, C56.1, C57.1, L2.2, R41.1, U1.F6 (VCCAUX), U1.F15 (VCCAUX), U1.P6 (VCCAUX), U1.P15 (VCCAUX)
+3V3: C31.1, C32.1, C33.1, C42.1, C43.1, C44.1, C51.1, C52.1, C53.1, C54.1, L3.2, R43.1, U1.F9 (VCCIO0), U1.F10 (VCCIO0), U1.F11 (VCCIO1), U1.F12 (VCCIO1), U1.H6 (VCCIO7), U1.H7 (VCCIO7), U1.H14 (VCCIO2), U1.H15 (VCCIO2), U1.J6 (VCCIO7), U1.J15 (VCCIO2), U1.L6 (VCCIO6), U1.L7 (VCCIO6), U1.L14 (VCCIO3), U1.L15 (VCCIO3), U1.M6 (VCCIO6), U1.M15 (VCCIO3), U1.P9 (VCCIO8), U1.P10 (VCCIO8); also elsewhere on the board
+5V: C34.1, C45.1, C50.1, U7.1 (EN), U7.4 (VIN), U8.1 (EN), U8.4 (VIN), U9.1 (EN), U9.4 (VIN); also elsewhere on the board
GND: C31.2, C32.2, C33.2, C34.2, C36.2, C37.2, C38.2, C39.2, C40.2, C41.2, C42.2, C43.2, C44.2, C45.2, C47.2, C48.2, C49.2, C50.2, C52.2, C53.2, C54.2, C55.2, C56.2, C57.2, R40.2, R42.2, R44.2, TP1.1, TP2.1, U1.B7 (GND), U1.B14 (GND), U1.C19 (GND), U1.D4 (GND), U1.F7 (GND), U1.F8 (GND), U1.F13 (GND), U1.F14 (GND), U1.G4 (GND), U1.G6 (GND), U1.G7 (GND), U1.G8 (GND), U1.G9 (GND), U1.G10 (GND), U1.G11 (GND), U1.G12 (GND), U1.G13 (GND), U1.G14 (GND), U1.G15 (GND), U1.G17 (GND), U1.H19 (GND), U1.J2 (GND), U1.J7 (GND), U1.J9 (GND), U1.J10 (GND), U1.J11 (GND), U1.J12 (GND), U1.J14 (GND), U1.K6 (GND), U1.K7 (GND), U1.K9 (GND), U1.K10 (GND), U1.K11 (GND), U1.K12 (GND), U1.K14 (GND), U1.K15 (GND), U1.L9 (GND), U1.L10 (GND), U1.L11 (GND), U1.L12 (GND), U1.M2 (GND), U1.M7 (GND), U1.M9 (GND), U1.M10 (GND), U1.M11 (GND), U1.M12 (GND), U1.M14 (GND), U1.M16 (GND), U1.N6 (GND), U1.N7 (GND), U1.N14 (GND), U1.N15 (GND), U1.P7 (GND), U1.P8 (GND), U1.P11 (GND), U1.P12 (GND), U1.P13 (GND), U1.P14 (GND), U1.R19 (GND), U1.T6 (GND), U1.T7 (GND), U1.T8 (GND), U1.T9 (GND), U1.T10 (GND), U1.U6 (GND), U1.U7 (GND), U1.U8 (GND), U1.U9 (GND), U1.U10 (GND), U1.U11 (GND), U1.U12 (GND), U1.U13 (GND), U1.U14 (GND), U1.V5 (GND), U1.V6 (GND), U1.V7 (GND), U1.V8 (GND), U1.V9 (GND), U1.V10 (GND), U1.V11 (GND), U1.V12 (GND), U1.V13 (GND), U1.V14 (GND), U1.V15 (GND), U1.V16 (GND), U1.V19 (GND), U1.V20 (GND), U1.W6 (GND), U1.W7 (GND), U1.W12 (GND), U1.W15 (GND), U1.W16 (GND), U1.W19 (GND), U1.Y5 (GND), U1.Y6 (GND), U1.Y7 (GND), U1.Y8 (GND), U1.Y11 (GND), U1.Y12 (GND), U7.2 (GND), U8.2 (GND), U9.2 (GND); also elsewhere on the board
unnamed: C35.2, R39.2, R40.1, U7.5 (FB)
unnamed: L1.1, U7.3 (SW)
unnamed: C46.2, R41.2, R42.1, U8.5 (FB)
unnamed: L2.1, U8.3 (SW)
unnamed: C51.2, R43.2, R44.1, U9.5 (FB)
unnamed: L3.1, U9.3 (SW)

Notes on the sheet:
Power
(15k/3.3k+1)*0.6V = 3.32V
(15k/18k+1)*0.6V = 1.1V
(15k/4.7k+1)*0.6V = 2.51V
Power: 1.1V, 2.5V, 3.3V

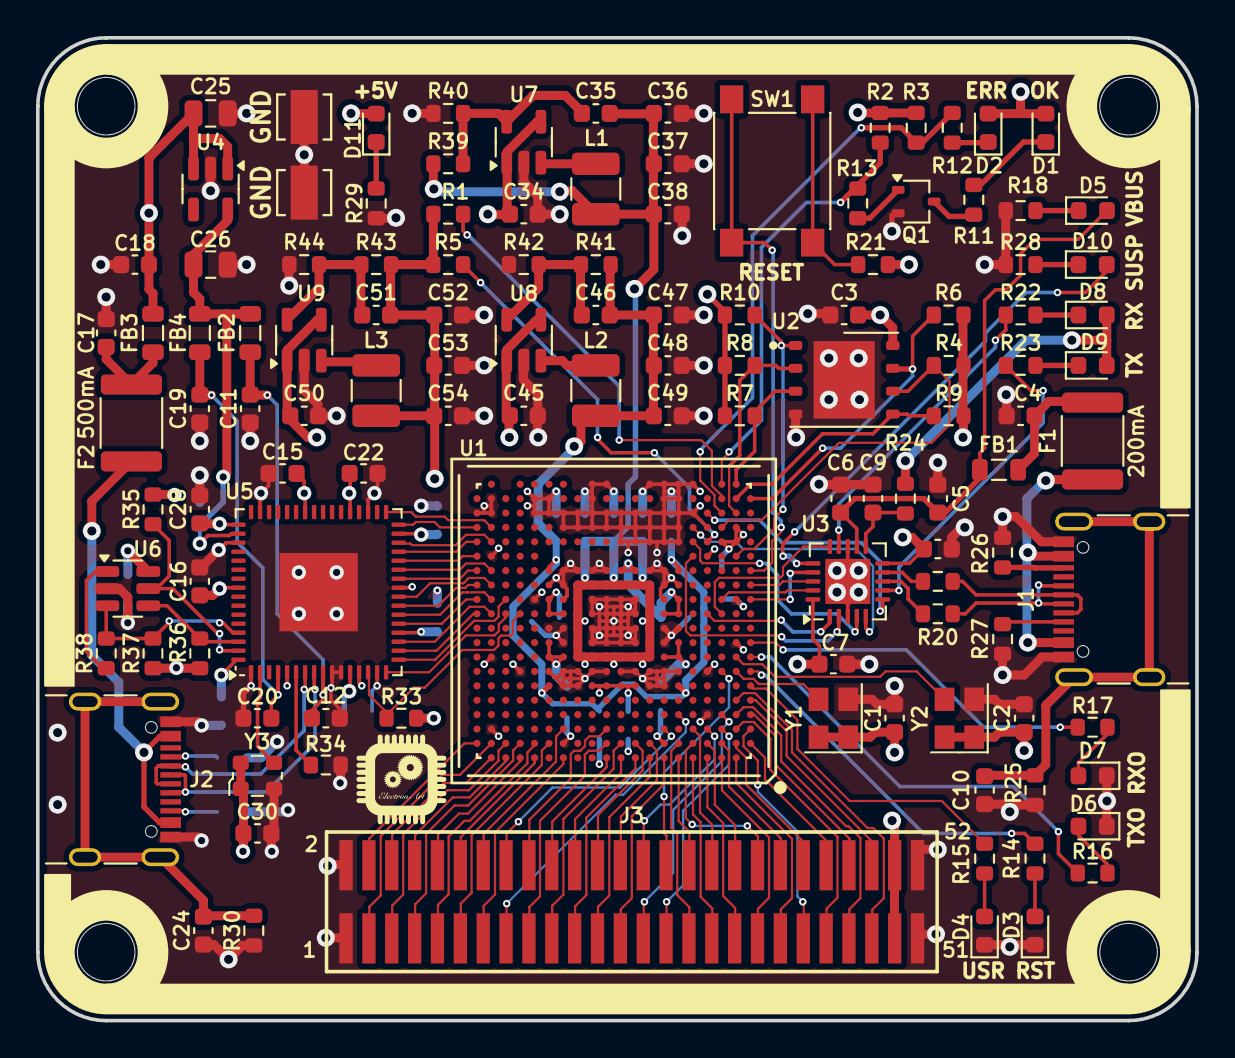
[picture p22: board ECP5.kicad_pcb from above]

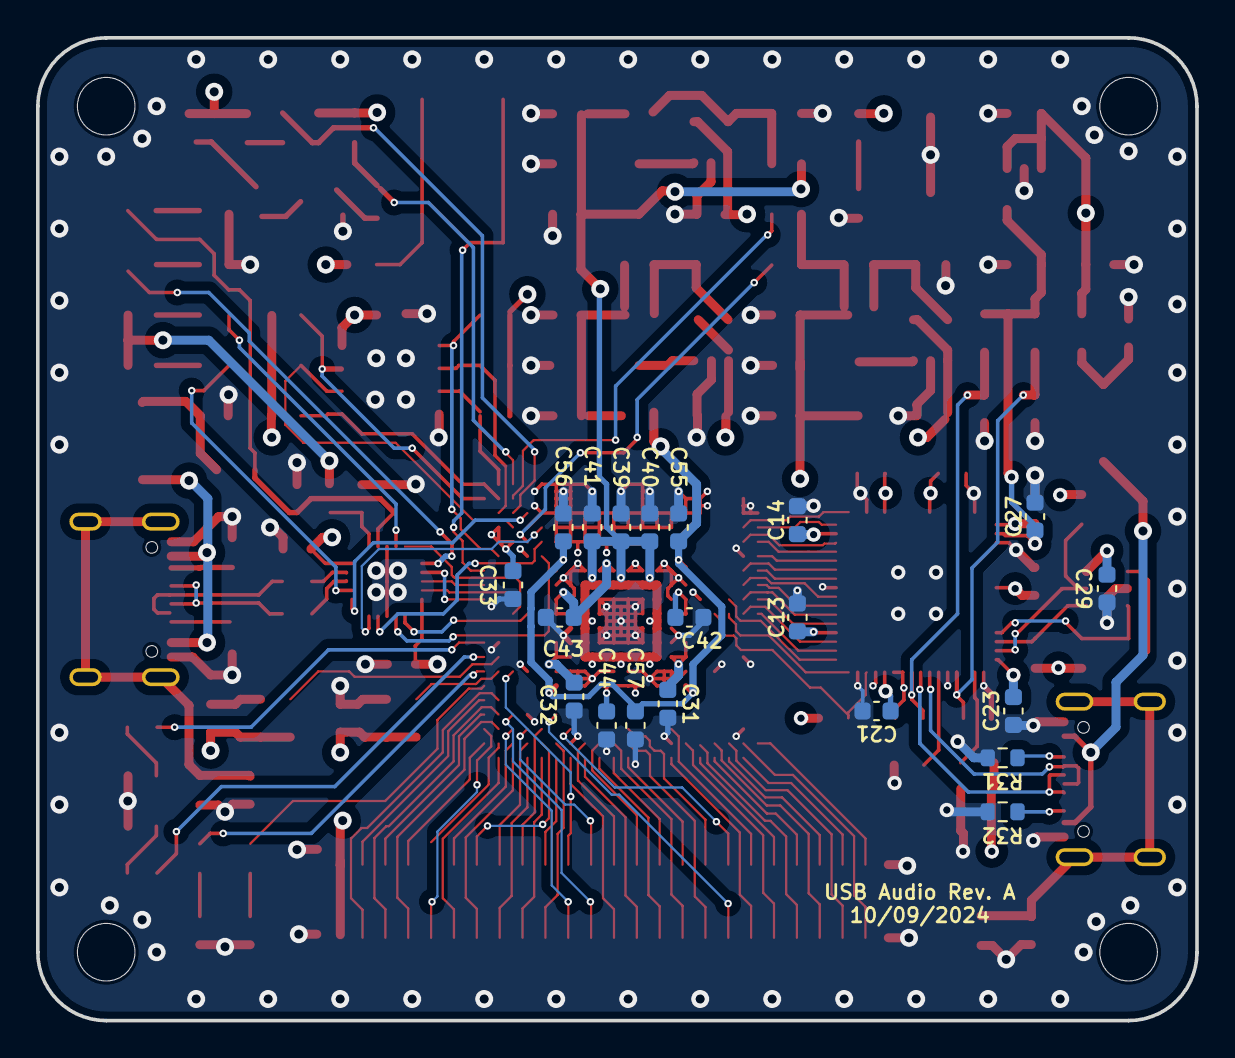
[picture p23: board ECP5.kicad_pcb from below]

Board: 4 copper layers, 64.4 x 54.6 mm, 144 parts (20 on the bottom side), 145 nets.

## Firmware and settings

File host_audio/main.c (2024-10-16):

/***********************************************************************************************************************
 * Copyright (c) 2024 Virgil Dobjanschi dobjanschivirgil@gmail.com
 *
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
 * THE SOFTWARE IS PROVIDED "AS IS", WITHOUT WARRANTY OF ANY KIND, EXPRESS OR IMPLIED, INCLUDING BUT NOT LIMITED TO THE
 * WARRANTIES OF MERCHANTABILITY, FITNESS FOR A PARTICULAR PURPOSE AND NONINFRINGEMENT. IN NO EVENT SHALL THE AUTHORS
 * OR COPYRIGHT HOLDERS BE LIABLE FOR ANY CLAIM, DAMAGES OR OTHER LIABILITY, WHETHER IN AN ACTION OF CONTRACT, TORT OR
 * OTHERWISE, ARISING FROM, OUT OF OR IN CONNECTION WITH THE SOFTWARE OR THE USE OR OTHER DEALINGS IN THE SOFTWARE.
 **********************************************************************************************************************/
#include <stdio.h>
#include <stdlib.h>
#include <unistd.h>
#include <string.h>
#include <sys/time.h>

#include "WinTypes.h"
#include "ftd2xx.h"
#include "wav_reader.h"
//======================================================================================================================
// FPGA definitions (see hdl_audio/definitions.sv)
// Bit rates
#define BIT_DEPTH_DOP       0x00
#define BIT_DEPTH_16        0x01
#define BIT_DEPTH_24        0x02
#define BIT_DEPTH_32        0x03

// Sample rate
// CMD_SETUP_OUTPUT payload byte[0] bits[4:2]
#define STREAM_44100_HZ    0x00
#define STREAM_88200_HZ    0x04
#define STREAM_176400_HZ   0x08
#define STREAM_352800_HZ   0x0c

#define STREAM_48000_HZ    0x10
#define STREAM_96000_HZ    0x14
#define STREAM_192000_HZ   0x18
#define STREAM_384000_HZ   0x1c

// Commands from the host to the FPGA.
// Command byte bits[7:5]. Bits[4:0] represent the length of the frame.
#define CMD_HOST_SETUP_OUTPUT      0x00
#define CMD_HOST_STREAM_OUTPUT     0x40
#define CMD_HOST_STOP              0x60

// Commands from the FPGA to the host.
#define CMD_FPGA_STOPPED           0x60

//======================================================================================================================
int rx_data (unsigned char* rx_buffer, unsigned int rx_bytes, unsigned char* pStopped);
int tx_data (FILE* fp, struct wav_header wh, unsigned int packet_length, unsigned char output_port,
                        unsigned char* tx_buffer, unsigned int* tx_bytes_to_send);

//======================================================================================================================
#define STATE_RX_CMD               1
#define STATE_RX_STOPPED_PAYLOAD   2
#define STATE_RX_DONE              3
unsigned char rx_state_m = STATE_RX_CMD;

//======================================================================================================================
#define STATE_TX_START_CMD         1
#define STATE_TX_STREAM_CMD        2
#define STATE_TX_STOP_CMD          3
#define STATE_TX_DONE              4
unsigned char tx_state_m = STATE_TX_START_CMD;
//unsigned int tx_total_bytes_read;

//======================================================================================================================
int main(int argc, char *argv[])
{
    int opt;
    char* filename;
    unsigned int packet_length = 8192; // Default packet length
    unsigned char output_port = 0;
    if (argc <= 1) {
        printf("Usage: %s -f <file name> -o <output port 0..3> -p <packet length 1..16383>\r\n", argv[0]);
        return 1;
    } else {
        while ((opt = getopt(argc, argv, "f:p:o:")) != -1) {
            switch (opt) {
                case 'f': filename = argv[2]; break;
                case 'o': output_port = strtol (argv[4], NULL, 10); break;
                case 'p': packet_length = strtol (argv[6], NULL, 10); break;
                default: {
                    printf("Usage: %s -f <file name> -o <output port 0..3> -p <packet length 1..16383>\r\n", argv[0]);
                    return 1;
                }
            }
        }
    }

    // Open the wav file
    FILE* fp = fopen(filename, "rb");
    if (fp == NULL) {
        printf("Cannot open file: %s\r\n", filename);
        return 1;
    }

    // Read the wav header
    struct wav_header wh;
    memset(&wh, 0, sizeof(struct wav_header));
    if (read_wav_file (fp, &wh) != 0) {
        printf("Invalid WAV file: %s\r\n", filename);
        fclose(fp);
        return 1;
    }

    FT_HANDLE ftHandle;
    FT_STATUS ftStatus;
    unsigned char Mask = 0xff;
    unsigned char Mode;

    ftStatus = FT_Open(0, &ftHandle);
    if(ftStatus != FT_OK) {
        // FT_Open failed return;
        printf("FT_Open failed! %d\r\n", ftStatus);
        fclose(fp);
        return 1;
    }

    // Set interface into FT245 Synchronous FIFO mode
    Mode = 0x00; //reset mode
    ftStatus = FT_SetBitMode(ftHandle, Mask, Mode);
    if (ftStatus != FT_OK) {
        printf("FT_SetBitMode RESET failed! %d\r\n", ftStatus);
        FT_Close(ftHandle);
        fclose(fp);
        return 1;
    }

    usleep(1000000);

    Mode = 0x40; // Sync FIFO mode
    ftStatus = FT_SetBitMode(ftHandle, Mask, Mode);
    if (ftStatus != FT_OK) {
        // FT_SetBitMode FAILED!
        printf("FT_SetBitMode SYNC FIFO MODE failed! %d\r\n", ftStatus);
        FT_Close(ftHandle);
        fclose(fp);
        return 1;
    }

    FT_SetLatencyTimer(ftHandle, 2);
    FT_SetUSBParameters(ftHandle,packet_length, packet_length);
    FT_SetFlowControl(ftHandle, FT_FLOW_RTS_CTS, 0x0, 0x0);
    FT_Purge(ftHandle, FT_PURGE_RX);

    // Send the data.
    unsigned int EventStatus;
    unsigned int rx_bytes;
    unsigned int tx_bytes;
    unsigned int rx_bytes_received;
    unsigned int tx_bytes_to_send = 0;
    unsigned int tx_bytes_written;
    unsigned int rx_total_bytes_received = 0;
    unsigned int tx_total_bytes_sent = 0;

    unsigned char* tx_buffer = malloc (packet_length);
    if (tx_buffer == NULL) {
        printf("Cannot allocate Tx buffer: %d\r\n", packet_length);
        fclose(fp);
        FT_Close(ftHandle);
        return 1;
    }

    unsigned char* rx_buffer = malloc (packet_length);
    if (rx_buffer == NULL) {
        printf("Cannot allocate Rx buffer: %d\r\n", packet_length);
        free (tx_buffer);
        fclose(fp);
        FT_Close(ftHandle);
        return 1;
    }

    printf("Start streaming %s to output port: %d. Packet length is %d bytes.\r\n",
                    filename, output_port, packet_length);
    // Get the start time
    struct timeval tv_start;
    gettimeofday(&tv_start, NULL);
    long long start_ms = tv_start.tv_sec*1000LL + tv_start.tv_usec/1000;

    unsigned char rx_stopped = 0;
    while (1) {
        ftStatus = FT_GetStatus (ftHandle, &rx_bytes, &tx_bytes, &EventStatus);
        if (ftStatus != FT_OK) {
            printf("FT_GetStatus failed! %d\r\n", ftStatus);
            break;
        }

        if (rx_bytes > 0) {
            if (rx_bytes > packet_length) {
                rx_bytes = packet_length;
            }

            ftStatus = FT_Read(ftHandle, rx_buffer, rx_bytes, &rx_bytes_received);
            if (ftStatus != FT_OK || rx_bytes_received != rx_bytes) {
                printf("FT_Read failed! ftStatus = %d; Bytes requested: %d, Bytes received: %d\r\n",
                                    ftStatus, rx_bytes, rx_bytes_received);
                break;
            }

            rx_total_bytes_received += rx_bytes_received;
            if (rx_data (rx_buffer, rx_bytes, &rx_stopped) < 0) {
                break;
            }

            if (rx_stopped == 1) {
                break;
            }
        }

        if (tx_bytes_to_send == 0) {
            if (tx_data (fp, wh, packet_length, output_port, tx_buffer, &tx_bytes_to_send) < 0) {
                break;
            }
        }

        if (tx_bytes_to_send > 0 && packet_length - tx_bytes >= tx_bytes_to_send) {
            ftStatus = FT_Write(ftHandle, tx_buffer, tx_bytes_to_send, &tx_bytes_written);
            //printf("%d\r\n", tx_bytes_written);
            if (ftStatus != FT_OK || tx_bytes_written != tx_bytes_to_send) {
                printf("FT_Write failed! ftStatus = %d; Bytes to send: %d, Bytes sent: %d\r\n",
                                    ftStatus, tx_bytes_to_send, tx_bytes_written);
                break;
            }

            tx_total_bytes_sent += tx_bytes_written;

            // This buffer was sent
            tx_bytes_to_send = 0;
        }
    }

    // Get the stop time
    struct timeval tv_stop;
    gettimeofday(&tv_stop, NULL);
    long long stop_ms = tv_stop.tv_sec*1000LL + tv_stop.tv_usec/1000;
    long duration = (long)(stop_ms - start_ms);

    printf("%d bytes sent, %d bytes received in %ld ms. Tx: %ld KBps, Rx: %ld KBps\r\n",
                tx_total_bytes_sent, rx_total_bytes_received, duration, tx_total_bytes_sent / duration,
                rx_total_bytes_received / duration);
    // Cleanup
    free (tx_buffer);
    free (rx_buffer);
    FT_Close(ftHandle);
    fclose(fp);
    return 0;
}

//======================================================================================================================
int tx_data (FILE* fp, struct wav_header wh, unsigned int packet_length, unsigned char output_port,
                        unsigned char* tx_buffer, unsigned int* tx_bytes_to_send) {
    switch (tx_state_m) {
        case STATE_TX_START_CMD: {
            switch (wh.fmt_subchunk.num_channels) {
                case 2: break; // Only two channels are supported. Mono will be supported later.
                default: {
                    printf("Unsupported number of channels: %d\r\n", wh.fmt_subchunk.num_channels);
                    return -1;
                }
            }

            tx_buffer[0] = CMD_HOST_SETUP_OUTPUT | 1;
            // Set the bit depth
            switch (wh.fmt_subchunk.bits_per_sample) {
                case 16: tx_buffer[1] = BIT_DEPTH_16; break;
                case 24: tx_buffer[1] = BIT_DEPTH_24; break;
                case 32: tx_buffer[1] = BIT_DEPTH_32; break;
                default: {
                    printf("Unsupported bit depth: %d\r\n", wh.fmt_subchunk.bits_per_sample);
                    return -2;
                }
            }

            // Set the sampling rate
            switch (wh.fmt_subchunk.sample_rate) {
                case 44100: tx_buffer[1] |= STREAM_44100_HZ; break;
                case 88200: tx_buffer[1] |= STREAM_88200_HZ; break;
                case 176400: tx_buffer[1] |= STREAM_176400_HZ; break;
                case 352800: tx_buffer[1] |= STREAM_352800_HZ; break;

                case 48000: tx_buffer[1] |= STREAM_48000_HZ; break;
                case 96000: tx_buffer[1] |= STREAM_96000_HZ; break;
                case 192000: tx_buffer[1] |= STREAM_192000_HZ; break;
                case 384000: tx_buffer[1] |= STREAM_384000_HZ; break;

                default: {
                    printf("Unsupported sample rate %d bytes\r\n", wh.fmt_subchunk.sample_rate);
                    return -3;
                }
            }

            // Set the output_port
            tx_buffer[1] |= output_port << 6;

            *tx_bytes_to_send = 2;

            tx_state_m = STATE_TX_STREAM_CMD;
            //tx_total_bytes_read = 0;
            break;
        }

        case STATE_TX_STREAM_CMD: {
            size_t bytes_read;
            bytes_read = fread(tx_buffer + 3, 1, packet_length - 3, fp);
            //printf("Read %ld bytes, requested %d\r\n", (unsigned long) bytes_read, packet_length);
            //tx_total_bytes_read += bytes_read;
            //printf("Read total %d bytes\r\n", tx_total_bytes_read);
            if (bytes_read > 0) {
                tx_buffer[0] = CMD_HOST_STREAM_OUTPUT | 0x10;
                tx_buffer[1] = (unsigned char)(bytes_read >> 8);
                tx_buffer[2] = (unsigned char)bytes_read;
                *tx_bytes_to_send = 3 + bytes_read;
            } else {
                *tx_bytes_to_send = 0;
                tx_state_m = STATE_TX_STOP_CMD;
            }

            break;
        }

        case STATE_TX_STOP_CMD: {
            tx_buffer[0] = CMD_HOST_STOP;
            *tx_bytes_to_send = 1;

            tx_state_m = STATE_TX_DONE;
            break;
        }

        case STATE_TX_DONE: {
            *tx_bytes_to_send = 0;
            break;
        }
    }

    return 0;
}

//======================================================================================================================
int rx_data (unsigned char* rx_buffer, unsigned int rx_bytes, unsigned char* pStopped) {

    unsigned char rx_cmd;
    unsigned char rx_payload_length;

    for (unsigned int i = 0; i < rx_bytes; i++) {
        switch (rx_state_m) {
            case STATE_RX_CMD: {
                rx_cmd = rx_buffer[i] & 0xe0;
                rx_payload_length = rx_buffer[i] & 0x1f;
                switch (rx_cmd) {
                    case CMD_FPGA_STOPPED: {
                        if (rx_payload_length == 1) {
                            printf("CMD_FPGA_STOPPED with payload: %d\r\n", rx_payload_length);
                            rx_state_m = STATE_RX_STOPPED_PAYLOAD;
                        } else {
                            printf("CMD_FPGA_STOPPED invalid payload: %d\r\n", rx_payload_length);
                            return -1;
                        }

                        break;
                    }

                    default: {
                        printf("Bad command: %d with payload: %d\r\n", rx_cmd, rx_payload_length);
                        return -2;
                    }
                }

                break;
            }

            case STATE_RX_STOPPED_PAYLOAD: {
                    if (rx_buffer[i] == 0) {
                        printf("===== Test OK =====\r\n");
                    } else {
                        printf("===== Test failed (error code %d) =====\r\n", rx_buffer[i]);
                    }

                    rx_state_m = STATE_RX_DONE;
                    *pStopped = 1;
                break;
            }

            case STATE_RX_DONE: {
                *pStopped = 1;
                break;
            }
        }
    }

    return 0;
}

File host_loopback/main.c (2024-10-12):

/***********************************************************************************************************************
 * Copyright (c) 2024 Virgil Dobjanschi dobjanschivirgil@gmail.com
 *
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
 * THE SOFTWARE IS PROVIDED "AS IS", WITHOUT WARRANTY OF ANY KIND, EXPRESS OR IMPLIED, INCLUDING BUT NOT LIMITED TO THE
 * WARRANTIES OF MERCHANTABILITY, FITNESS FOR A PARTICULAR PURPOSE AND NONINFRINGEMENT. IN NO EVENT SHALL THE AUTHORS
 * OR COPYRIGHT HOLDERS BE LIABLE FOR ANY CLAIM, DAMAGES OR OTHER LIABILITY, WHETHER IN AN ACTION OF CONTRACT, TORT OR
 * OTHERWISE, ARISING FROM, OUT OF OR IN CONNECTION WITH THE SOFTWARE OR THE USE OR OTHER DEALINGS IN THE SOFTWARE.
 **********************************************************************************************************************/
#include <stdio.h>
#include <stdlib.h>
#include <unistd.h>
#include <sys/time.h>

#include "ftd2xx.h"

//======================================================================================================================
BOOL rx_data (unsigned int packet_count, unsigned int packet_bytes, unsigned char* rx_buffer, unsigned int rx_bytes,
                    unsigned char verbose);
BOOL tx_data (unsigned int packet_count, unsigned int packet_bytes, unsigned char* tx_buffer,
                    unsigned int* tx_bytes_to_send, unsigned char verbose);

#define USB_BUFFER_SIZE 0x10000
//======================================================================================================================
#define RX_BUFFER_SIZE USB_BUFFER_SIZE
unsigned int bytes_received = 0;
//======================================================================================================================
#define TX_BUFFER_SIZE USB_BUFFER_SIZE
unsigned char out_data = 0;
unsigned char in_data = 0;
BOOL run_test = TRUE;
unsigned int packets_sent = 0;


//======================================================================================================================
int main(int argc, char *argv[]) {
    int opt;
    unsigned int packet_count = 1;
    unsigned int packet_bytes = 1;
    unsigned char verbose = 0;
    if (argc <= 1) {
        printf("Usage: %s [-p <bytes per packet> -c <count of packets> -v]\r\n", argv[0]);
        return 1;
    } else {
        while ((opt = getopt(argc, argv, "c:p:v")) != -1) {
            switch (opt) {
                case 'c': packet_count = strtol (argv[2], NULL, 10); break;
                case 'p': packet_bytes = strtol (argv[4], NULL, 10); break;
                case 'v': verbose = 1; break;
                default: {
                    printf("Usage: %s [-p <bytes per packet> -c <count of packets> -v]\r\n", argv[0]);
                    return 1;
                }
            }
        }
    }

    if (verbose) {
        printf("Packet count: %d, packet bytes: %d\r\n", packet_count, packet_bytes);
    }

    if (packet_bytes > TX_BUFFER_SIZE) {
        printf("Packet size > TX_BUFFER_SIZE (%d)\r\n", TX_BUFFER_SIZE);
        return 1;
    }

    FT_HANDLE ftHandle = NULL;
    FT_STATUS ftStatus;
    unsigned char Mask = 0xff;
    unsigned char Mode;

    ftStatus = FT_Open(0, &ftHandle);
    if(ftStatus != FT_OK) {
        printf("FT_Open failed! %d\r\n", ftStatus);
        return 1;
    }

    // Set interface into FT245 Synchronous FIFO mode
    Mode = 0x00; //reset mode
    ftStatus = FT_SetBitMode(ftHandle, Mask, Mode);
    if (ftStatus != FT_OK) {
        printf("FT_SetBitMode RESET failed! %d\r\n", ftStatus);
        FT_Close(ftHandle);
        return 1;
    }

    usleep(1000000);

    Mode = 0x40; // Sync FIFO mode
    ftStatus = FT_SetBitMode(ftHandle, Mask, Mode);
    if (ftStatus != FT_OK) {
        printf("FT_SetBitMode SYNC FIFO MODE failed! %d\r\n", ftStatus);
        FT_Close(ftHandle);
        return 1;
    }

    FT_SetLatencyTimer(ftHandle, 2);
    FT_SetUSBParameters(ftHandle, USB_BUFFER_SIZE, USB_BUFFER_SIZE);
    FT_SetFlowControl(ftHandle, FT_FLOW_RTS_CTS, 0x0, 0x0);
    FT_Purge(ftHandle, FT_PURGE_RX | FT_PURGE_TX);

    unsigned int EventStatus;
    unsigned int rx_bytes, tx_bytes;
    unsigned int rx_bytes_received;
    unsigned char rx_buffer[RX_BUFFER_SIZE];
    unsigned char tx_buffer[TX_BUFFER_SIZE];

    unsigned int tx_bytes_to_send = 0, tx_bytes_written;
    unsigned int rx_total_bytes_received = 0;
    unsigned int tx_total_bytes_sent = 0;

    // Get the start time
    struct timeval tv_start;
    gettimeofday(&tv_start, NULL);
    long long start_ms = tv_start.tv_sec*1000LL + tv_start.tv_usec/1000;

    while (1) {
        ftStatus = FT_GetStatus (ftHandle, &rx_bytes, &tx_bytes, &EventStatus);
        if (ftStatus != FT_OK) {
            printf("FT_GetStatus failed! %d\r\n", ftStatus);
            FT_Close(ftHandle);
            return 1;
        }

        if (rx_bytes > 0) {
            if (rx_bytes > RX_BUFFER_SIZE) {
                rx_bytes = RX_BUFFER_SIZE;
            }

            ftStatus = FT_Read(ftHandle, rx_buffer, rx_bytes, &rx_bytes_received);
            if (verbose) {
                printf("RD: %d\r\n", rx_bytes_received);
            }
            if (ftStatus != FT_OK || rx_bytes_received != rx_bytes) {
                printf("FT_Read failed! ftStatus = %d; Bytes requested: %d, Bytes received: %d\r\n",
                                    ftStatus, rx_bytes, rx_bytes_received);
                FT_Close(ftHandle);
                return 1;
            }

            rx_total_bytes_received += rx_bytes_received;
            if (FALSE == rx_data (packet_count, packet_bytes, rx_buffer, rx_bytes, verbose)) {
                break;
            }
        }
        if (tx_bytes_to_send == 0) {
            tx_data (packet_count, packet_bytes, tx_buffer, &tx_bytes_to_send, verbose);
        }

        if (tx_bytes_to_send > 0 && USB_BUFFER_SIZE - tx_bytes >= tx_bytes_to_send) {
            ftStatus = FT_Write(ftHandle, tx_buffer, tx_bytes_to_send, &tx_bytes_written);

            if (ftStatus != FT_OK || tx_bytes_written != tx_bytes_to_send) {
                printf("FT_Write failed! ftStatus = %d; Bytes to send: %d, Bytes sent: %d\r\n",
                                    ftStatus, tx_bytes_to_send, tx_bytes_written);
                FT_Close(ftHandle);
                return 1;
            }

            if (verbose) {
                printf("WR: %d\r\n", tx_bytes_written);
            }

            tx_total_bytes_sent += tx_bytes_written;
/*
            // If we don't want to wait for the loopback data this code is useful in breaking out of the while loop.
            if (tx_total_bytes_sent == packet_bytes * packet_count) {
                break;
            }
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

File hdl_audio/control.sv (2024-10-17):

/***********************************************************************************************************************
 * Copyright (c) 2024 Virgil Dobjanschi dobjanschivirgil@gmail.com
 *
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
 * THE SOFTWARE IS PROVIDED "AS IS", WITHOUT WARRANTY OF ANY KIND, EXPRESS OR IMPLIED, INCLUDING BUT NOT LIMITED TO THE
 * WARRANTIES OF MERCHANTABILITY, FITNESS FOR A PARTICULAR PURPOSE AND NONINFRINGEMENT. IN NO EVENT SHALL THE AUTHORS
 * OR COPYRIGHT HOLDERS BE LIABLE FOR ANY CLAIM, DAMAGES OR OTHER LIABILITY, WHETHER IN AN ACTION OF CONTRACT, TORT OR
 * OTHERWISE, ARISING FROM, OUT OF OR IN CONNECTION WITH THE SOFTWARE OR THE USE OR OTHER DEALINGS IN THE SOFTWARE.
 **********************************************************************************************************************/

 /***********************************************************************************************************************
 * This module implements the reading out of the async FIFO at the appropriate audio frequency and sends the audio
 * samples to the digital audio module. It only supports playback at this time.
 **********************************************************************************************************************/
`timescale 1ps/1ps
`default_nettype none

`include "definitions.svh"

module control (
    input logic reset_i,
    input logic clk_24576000_i,
    input logic clk_22579200_i,
    // Input FIFO access
    output logic rd_in_fifo_clk_o,
    output logic rd_in_fifo_en_o,
    input logic rd_in_fifo_empty_i,
    input logic [7:0] rd_in_fifo_data_i,
    // Output FIFO ports
    output logic wr_out_fifo_clk_o,
    output logic wr_out_fifo_en_o,
    output logic [7:0] wr_out_fifo_data_o,
    input logic wr_out_fifo_full_i,
    input logic wr_out_fifo_afull_i,
    // Audio output
    output logic spdif_o,
    output logic i2s_sdata_o,
    output logic i2s_bclk_o,
    output logic i2s_lrck_o,
    output logic i2s_mclk_o,
    output logic dsd_o,
    // Sample rate LEDs
    output logic led_ctrl_err_o,
    output logic led_sr_48000Hz_o,
    output logic led_sr_96000Hz_o,
    output logic led_sr_192000Hz_o,
    output logic led_sr_384000Hz_o,
    output logic led_sr_44100Hz_o,
    output logic led_sr_88200Hz_o,
    output logic led_sr_176400Hz_o,
    output logic led_sr_352800Hz_o,
    // Bit depth LEDs
    output logic led_br_dop_o,
    output logic led_br_16_bit_o,
    output logic led_br_24_bit_o,
    output logic led_br_32_bit_o,
    // Streaming status
    output logic led_streaming_spdif_o,
    output logic led_streaming_i2s_o,
    // Test point
    output logic tp_control_1_o,
    output logic tp_control_2_o);

    // Assign test points as needed
    assign tp_control_1_o = pll_clocks_22579200[1];
    assign tp_control_2_o = pll_clocks_22579200[2];

    assign rd_in_fifo_clk_o = clk;
    assign wr_out_fifo_clk_o = clk;

`ifdef SIMULATION
    logic [2:0] pll_clocks_24576000;
    assign pll_clocks_24576000[0] = clk_24576000_i;
    // Max bit clock for 24 bit @24.576000 MHz
    localparam CLK_18432000_PS = 54253;
    always #(CLK_18432000_PS/2) pll_clocks_24576000[1] = ~pll_clocks_24576000[1];
    // Max frequency which is a multiple of 2 @24.576000 MHz
    localparam CLK_98304000_PS = 10172;
    always #(CLK_98304000_PS/2) pll_clocks_24576000[2] = ~pll_clocks_24576000[2];

    logic [2:0] pll_clocks_22579200;
    assign pll_clocks_22579200[0] = clk_22579200_i;
    // Max bit clock for 24 bit @22.579200 MHz
    localparam CLK_16934400_PS = 59051;
    always #(CLK_16934400_PS/2) pll_clocks_22579200[1] = ~pll_clocks_22579200[1];
    // Max frequency which is a multiple of 2 of @22.579200 MHz
    localparam CLK_90316800_PS = 11072;
    always #(CLK_90316800_PS/2) pll_clocks_22579200[2] = ~pll_clocks_22579200[2];
`else
    logic [2:0] pll_clocks_24576000;
    pll_24576000 pll_24576000_m(
        .CLKI (clk_24576000_i),
        .CLKOP(pll_clocks_24576000[0]),
        .CLKOS(pll_clocks_24576000[1]),
        .CLKOS2(pll_clocks_24576000[2]));

    logic [2:0] pll_clocks_22579200;
    pll_22579200 pll_22579200_m(
        .CLKI (clk_22579200_i),
        .CLKOP(pll_clocks_22579200[0]),
        .CLKOS(pll_clocks_22579200[1]),
        .CLKOS2(pll_clocks_22579200[2]));
`endif

    /*==================================================================================================================
    Bit clock frequencies for all supported I2S modes (2 channels).
    --------------------------------------------------------------------------------------------------------------------
    SR      16-bit      24-bit      32-bit      MCLK
    --------------------------------------------------------------------------------------------------------------------
    48000   1536000     2304000     3072000     12288000
    96000   3072000     4608000     6144000     24576000
    192000  6144000     9216000     12288000    49152000
    384000  12288000    18432000    24576000    98304000

    44100   1411200     2116800     2822400     11289600
    88200   2822400     4233600     5644800     22579200
    176400  5644800     8467200     11289600    45158400
    352800  11289600    16934400    22579200    90316800
    ==================================================================================================================*/

    // 32 bit @24.576000 MHz
    logic [3:0] clk_24576000_32;
    // 384 KHz 32 bit: 24576000 Hz
    assign clk_24576000_32[3] = clk_24576000_i;
    // 192 KHz 32 bit: 12288000 Hz
    divide_by_2 divide_by_2_1_m (reset_i, clk_24576000_32[3], clk_24576000_32[2]);
    // 96 KHz 32 bit: 6144000 Hz
    divide_by_2 divide_by_2_2_m (reset_i, clk_24576000_32[2], clk_24576000_32[1]);
    // 48 KHz 32 bit: 3072000 Hz
    divide_by_2 divide_by_2_3_m (reset_i, clk_24576000_32[1], clk_24576000_32[0]);

    // 24 bit @24.576000 MHz
    logic [3:0] clk_24576000_24;
    // 384 KHz 24 bit: 18432000 Hz
    assign clk_24576000_24[3] = pll_clocks_24576000[1];
    // 192 KHz 24 bit: 9216000 Hz
    divide_by_2 divide_by_2_4_m (reset_i, clk_24576000_24[3], clk_24576000_24[2]);
    // 96 KHz 24 bit: 4608000 Hz
    divide_by_2 divide_by_2_5_m (reset_i, clk_24576000_24[2], clk_24576000_24[1]);
    // 48 KHz 24 bit: 2304000 Hz
    divide_by_2 divide_by_2_6_m (reset_i, clk_24576000_24[1], clk_24576000_24[0]);

    // 16 bit @24.576000 MHz
    logic [3:0] clk_24576000_16;
    // 384 KHz 16 bit: 12288000 Hz
    assign clk_24576000_16[3] = clk_24576000_32[2];
    // 192 KHz 16 bit: 6144000 Hz
    assign clk_24576000_16[2] = clk_24576000_32[1];
    // 96 KHz 16 bit: 3072000 Hz
    assign clk_24576000_16[1] = clk_24576000_32[0];
    // 48 KHz 16 bit: 1536000 Hz
    divide_by_2 divide_by_2_7_m (reset_i, clk_24576000_16[1], clk_24576000_16[0]);
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

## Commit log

2024-09-02 Add KiCAD files
    [ECP5.kicad_pcb, ECP5.kicad_sch, Extension.kicad_sch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]
2024-09-02 Add footprints
2024-09-02 Add 3D models (part 1)
    [SAMTEC-FTS-126-02-X-DV.step, WSON8-6x5.STEP]
2024-09-02 Add 3D files (part 2)
    [0ZCG-0_70mm.STEP, 5197TR.step, CRYSTAL_7050-4.step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]
2024-09-02 Update FIFO label types
    [FT2232HQ_FIFO.kicad_sch]
2024-09-02 Changed the FT231X fuse
    [Flash_JTAG.kicad_sch]
2024-09-03 Updated USB D+/- routing
    [ECP5.kicad_pcb]
2024-09-03 Updated gitignore
    [Flash_JTAG.kicad_sch]
2024-09-03 Updated the names of the Sheets
    [FT2232HQ_FIFO.kicad_sch]
2024-09-03 Routing complete
    [ECP5.kicad_pcb, Extension.kicad_sch, FT2232HQ_FIFO.kicad_sch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]
2024-09-05 PCB changes
    [ECP5.kicad_pcb, FT2232HQ_FIFO.kicad_sch]
2024-09-06 Added 3D board view and schematic PDF
2024-09-06 Updated link to 3D board view and to PDF file.
2024-09-06 Changed the name of the project path
    [ECP5.kicad_pcb, Extension.kicad_sch, FT2232HQ_FIFO.kicad_sch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]
2024-09-07 Fixed the 3D model path for crystals
    [ECP5.kicad_pcb]
2024-09-07 Updated component descriptions
    [ECP5.kicad_pcb, FT2232HQ_FIFO.kicad_sch, Flash_JTAG.kicad_sch]
2024-09-13 Print messages formatting
2024-09-13 Cosmetic changes
    Added simulation rules in sim_ft2232.sv
    Modified print messages.
2024-09-15 Added command line parameters
    Added command line parameters for:
    1. Number of cycles for which the FT2232 simulator exhibits an empty FIFO mid way while sending data.
    2. Number of cycles for which the FT2232 simulator exhibits a full FIFO mid way while receiving data (test 2 only).
    3. The application clock period in pico seconds. This is useful for testing a faster path for FPGA -> FT2232.
2024-09-15 Fixed back pressure bug
    If FT2232 FIFO is full (FPGA -> FT2232) save two bytes to be retried later.
2024-09-16 Added streaming status LEDs
2024-09-17 Update tx_spdif.sv
    The Validity bit for a sub-frame == 1'b0 when data is valid.
2024-09-20 Added UART debugging support
2024-09-24 Added WAV files to generate Verilog streaming simulation file.
    The host code can generate bin files which can then be used by the Verilog simulator to simulate sending audio data over from FT2232. This ensures that whatever data is sent by the host app is interpreted correctly by the Verilog code.
    [main.c]
2024-09-25 Reassigned LEDs
    When the extension board is not present and the UART is not in use 3 main board LEDs are used to view errors and monitor reads and writes from/to FT2232.
    [control.sv]
2024-10-03 Added simple test
    [out.cfg]
2024-10-05 Loopback test
    [out.cfg]
2024-10-05 Remove intermmediary files.
    [out.cfg]
2024-10-12 Added the verbose flag and print statistics.
2024-10-12 Check if serial driver is loaded before unloading it.
2024-10-13 Print KBps
2024-10-13 Revert "Print KBps"
    This reverts commit 5f88469228545d3ee3575c75c73158e72251256a.
    [control.sv, main.c]
2024-10-13 Reapply "Print KBps"
    This reverts commit 67de362229a693b178d52761b90ad913fb7d8227.
    [control.sv, main.c]
2024-10-16 Added board extension support
2024-10-16 Fix FIFO read in case of error
    [control_test.sv]
2024-10-17 Fix the simulation clock generation
    [control.sv]

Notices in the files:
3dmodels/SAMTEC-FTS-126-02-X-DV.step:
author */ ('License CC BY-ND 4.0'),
